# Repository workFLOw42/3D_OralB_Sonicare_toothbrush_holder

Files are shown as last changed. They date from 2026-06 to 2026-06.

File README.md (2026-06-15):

# Elektrischer Zahnbürstenhalter – frei konfigurierbar (Oral-B + Sonicare)

**Eigenentwicklung**: ein parametrischer Halter mit **1–4 frei konfigurierbaren
Fächern** (je Oral-B/Sonicare × Ständer/Laden), **Voronoi-Relief** außen und
**austauschbaren Voronoi-Einsteckgittern**.
Die gesamte Geometrie ist eigenständig in OpenSCAD (parametrisch) + Python
(Voronoi-Erzeugung, 3MF-Packen) konstruiert. Übernommen wurden **keine fremden
Modelle** – lediglich die *funktionalen Schnittstellenmaße* (Ladeöffnungen,
Zapfen, Ladehöhen) wurden an Referenzteilen vermessen, damit die Ladestationen
und Bürsten von Oral-B und Sonicare passen.

<p align="center">
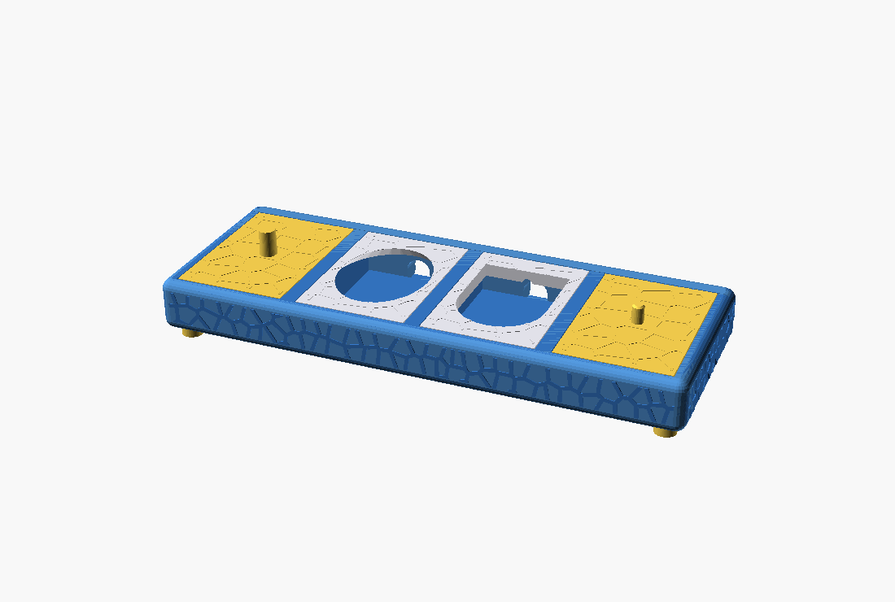
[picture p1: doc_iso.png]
Gesamtansicht
  <br>
  <em>Korpus mit den 4 eingesetzten Voronoi-Gittern</em>
</p>

## Über dieses Projekt

**Warum dieser Halter?**
Ladestationen für elektrische Zahnbürsten sind gerätespezifisch, und fertige Halter
passen meist nur zu *einem* Modell in *einer* Anordnung. Dieser Halter ist **frei
konfigurierbar**: 1–4 Fächer, je Fach wählbar für **Oral-B oder Sonicare** und als
**Ständer- oder Lade-Variante** – alles über Parameter, der Korpus wächst automatisch mit.

**Idee dahinter.**
Gleiches Design-Vokabular wie das Schwester-Projekt
[„Kabelbox"](https://github.com/workFLOw42/3D_Cable_box): **R5-Rundungen**, bündige
Flächen, **erhabenes Voronoi-Relief** und eine **werkzeuglose Schiebe-Mechanik**. Die
Funktionsflächen stecken in **austauschbaren Voronoi-Einsteckgittern**, die von hinten
eingeschoben werden – so lässt sich die Belegung später ändern, ohne den ganzen Korpus
neu zu drucken. Seit v2 sind die Einsätze **geschlossene Platten** mit dünnem, rein
optischem Voronoi-Relief (statt offenem Gitter).

**Status.** **Version 2.0** – funktionsfähig. Das jetzige Aussehen ist der Startpunkt;
das Projekt wird **bei Bedarf aktiv weiterentwickelt, überarbeitet und erweitert**
(weitere Geräte/Varianten, Feintuning der Spiele nach Probedrucken). Wie die Maße
zustande kommen, ist transparent in [`MEASUREMENTS.md`](MEASUREMENTS.md) dokumentiert.

---

## Inhalt
1. [Konzept](#konzept)
2. [Fächer-Belegung](#fächer-belegung)
3. [Maße](#maße)
4. [Funktionsprinzipien](#funktionsprinzipien)
5. [Projektdateien](#projektdateien)
6. [Bauen](#bauen)
7. [Parameter-Referenz](#parameter-referenz)
8. [Anpassen](#anpassen)
9. [Drucken](#drucken)
10. [Herkunft der Maße](#herkunft-der-maße)
11. [Lizenz](#lizenz)

---

## Konzept
- **Korpus** = rechteckige Wanne mit 4 Fächern in einer Reihe.
  - **Dünnes** Voronoi-**Relief** (erhaben, ~Lagen-dünn, rein optisch) auf Front + 2
    Seiten (Rückseite = Rückwand).
  - **Alle Außenkanten/Ecken mit R5 mm abgerundet**.
  - **Geschlossener Boden**; **hinten offen** für die einschiebbare Rückwand.
  - Steht auf **4 steckbaren Füßen** (separates Teil `foot.scad`, Ø10 × 5 mm + Zapfen
    Ø5 × 2 mm) – von unten in Bodensacklöcher gesteckt, stützenfrei.
- **Einsätze** = **geschlossene Platten** mit dünnem Voronoi-Relief obenauf,
  **von hinten eingeschoben** und per **Feder & Nut** gehalten (Schiebedeckel-Prinzip):
  seitliche **Lippen** an der Fach-Oberkante übergreifen die Einsatz-Oberkante → der
  Einsatz hebt sich beim Abziehen der Bürste **nicht** mehr mit. Oberseite bündig.
  - **Ständer**: zentraler **Zapfen** – die Bürste wird aufgesteckt.
  - **Laden**: Öffnung für die lose eingestellte Ladestation, die oben
    **flächenbündig mit dem Gitter** abschließt. Sonicare zusätzlich mit einer
    **halbrunden Kabelrinne** (5 × 2 mm) auf der Unterseite am geraden D-Ende.
  - **Ablage** (`tray`): komplett **geschlossene** Platte ohne Zapfen/Öffnung.
- **Rückwand** = separate Platte (10 mm tief, **bündig** mit den hinteren Eckpfosten)
  mit Voronoi-Relief, **von oben senkrecht** eingeschoben. Ihre **Feder vorn**
  (`rear_tongue_d`) greift in eine senkrechte Nut in den **massiven Eckpfosten**
  (Kabelbox-Stil) + Boden-Nut; dahinter ~5,7 mm Vollmaterial → sitzt **fest**. Sichert
  die Einsätze und trägt je Fach ein **kleines gerundetes Kabelloch** (12×9 mm).
- **Modular**: jedes Fach frei mit jedem passenden Gitter bestückbar; weitere
  Gitter-Varianten lassen sich leicht ergänzen.
- **Montage**: Ladestation in den Lade-Einsatz legen → Einsätze (inkl. Station) von
  **hinten** einschieben → Rückwand **von oben** einschieben. Demontage umgekehrt.
- **Orientierung**: mechanisch sind die Einsätze vorne/hinten symmetrisch (Lippe
  beidseitig). Nur der **Sonicare-Lade-Einsatz** hat eine Vorzugsrichtung – der
  **Bogen der D-Öffnung zeigt nach vorne**, die gerade Seite nach hinten (zur
  Rückwand). Ständer (runder Zapfen) und Oral-B-Laden (Ellipse) sind richtungsneutral.

---

## Fächer-Belegung (konfigurierbar)
**Anzahl Module (1–4) und Typ je Fach frei wählbar.** Standard 1×4, außen
**Ständer**, innen **Laden**:

| # | Position | Funktion | Marke | Öffnung / Feature | Gitter-Datei |
|---|---|---|---|---|---|
| 1 | außen | Ständer | Oral-B | ovaler Zapfen 8×9,6 → 7,5×9 mm | `grid0.stl` |
| 2 | innen | Laden | Oral-B | ovale Öffnung 42 × 55 mm (unten 45° aufgeweitet) | `grid1.stl` |
| 3 | innen | Laden | Sonicare | D-Kontur 40 × 55 mm (Halbkreis vorne) | `grid2.stl` |
| 4 | außen | Ständer | Sonicare | runder Zapfen Ø5,5 mm | `grid3.stl` |

Einstellbar in `params.scad`: `n_bays` (1–4) und `bay1..bay4`
(`stand_orb` / `charge_orb` / `stand_son` / `charge_son` / `tray` / `cup`). Der Korpus
passt seine Breite automatisch an. *(Hinweis: das Voronoi-Flächenrelief ist für 4 Fächer
vorberechnet und wird bei weniger Fächern vorne nur beschnitten; die Gitter-Muster
in den Fächern sind davon unabhängig.)*

<p align="center">
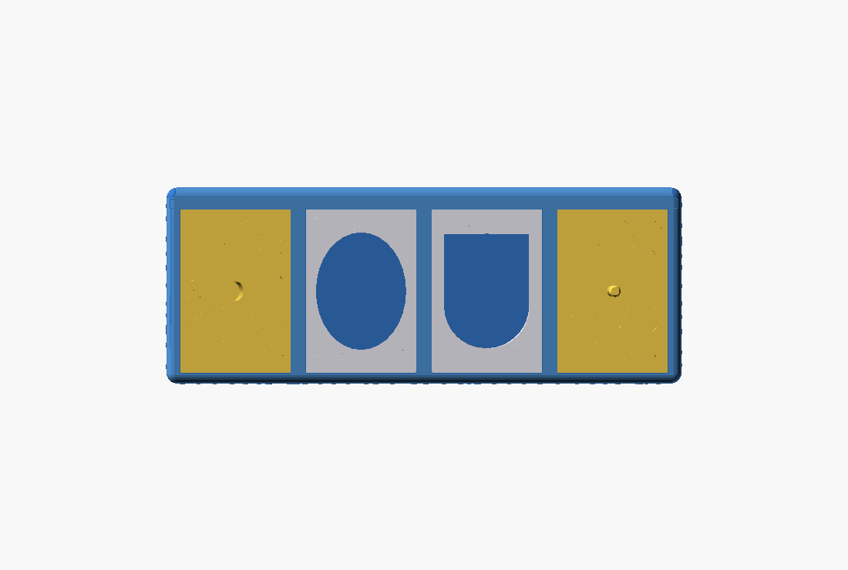
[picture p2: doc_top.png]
Draufsicht der 4 Fächer
  <br>
  <em>Draufsicht: Oral-B-Ständer (ovaler Zapfen) · Oral-B-Laden (Oval 41×54) ·
  Sonicare-Laden (D-Kontur 39×53) · Sonicare-Ständer (runder Zapfen Ø5,5)</em>
</p>

### Beispiel-Konfiguration: 2er (Becher + Ablage)
Ein fertig konfigurierter 2-Fach-Build (`n_bays=2`, `bay1="cup"`, `bay2="tray"`): ein
hoher **Becher** (Voronoi außen, gerundet, 80 mm) neben einer **Ablagefläche**
(geschlossen). Druckfertige Platte + Einzel-STLs liegen in
[`examples/2er-Becher-Ablage/`](examples/2er-Becher-Ablage)
(Platte 127,8 × 217,4 mm → passt auf X2D; Becher steht aufrecht, Rest liegt flach).

<p align="center">
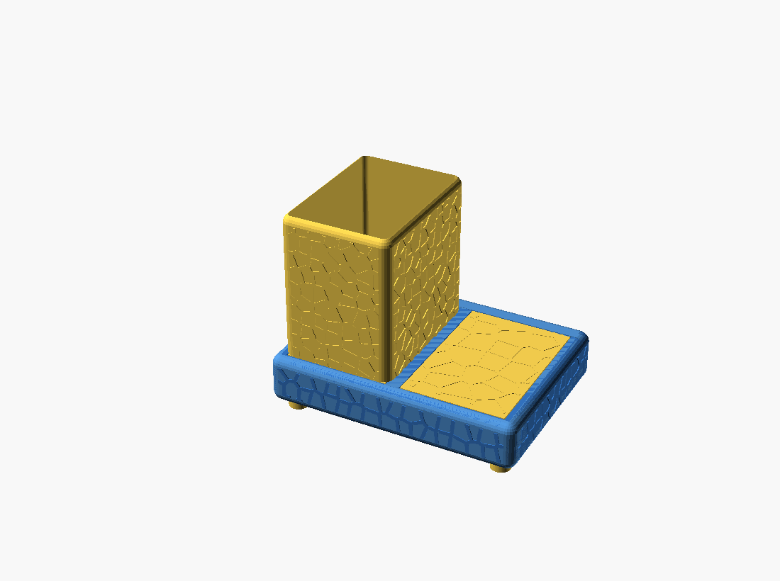
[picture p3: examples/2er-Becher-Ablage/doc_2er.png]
2er: Becher + Ablage
  <br>
  <em>2er: Becher (hoch, gerundet, Voronoi außen) + Ablagefläche (geschlossen)</em>
</p>

---

## Maße
| | Wert |
|---|---|
| Korpus außen (inkl. Relief) | **249,8 × 94,4 × 25 mm** (Wände v2 +1 mm) |
| + Füße | 5 mm → Gesamthöhe **30 mm** |
| Fach innen | 57 × 79 mm |
| Wandstärke | **5 mm** (Seitenwände) · zwei massive hintere Eckpfosten (10 mm) für die Rückwand-Nut · Boden 3 mm · Trennwand 3 mm |
| Kanten-/Eckradius | **R5 mm** (alle Außenkanten) |
| Füße (4×, steckbar) | Ø10 mm, 5 mm hoch + Zapfen Ø5 × 2 mm; Mitte 10 mm von den Rändern |
| Einsatz (geschlossene Platte) | 56,2 × ~79 × 6 mm + Zapfen/Öffnung, dünnes Relief oben |
| Druckplatte (alle Teile) | 249,8 × 196,6 mm → passt auf Bambu **X2D (256×256)** |

**Aus echten Referenzteilen gemessen** (Details → [Herkunft der Maße](#herkunft-der-maße)):

| Feature | Maß |
|---|---|
| Oral-B Laden (Ladering-Öffnung) | oval **41 × 54 mm** (Öffnung unten 45° aufgeweitet), Ladehöhe 21 mm |
| Oral-B Ständer-Zapfen | oval, verjüngt **8×10 → 7×9 mm**, h 14 mm |
| Sonicare Laden (Öffnung) | D-Kontur **39 × 53 mm** (Halbkreis vorne), Ladehöhe 20 mm; Kabelrinne 5×2 mm unten |
| Sonicare Ständer-Zapfen | rund **Ø 5,5 mm**, h 8,5 mm (Referenz Ø6,8) |

---

## Funktionsprinzipien

### Bündiges Laden
Lade-Fächer haben einen **erhöhten Boden** auf Höhe `body_height − charger_h`.
Die lose eingestellte Ladestation schließt damit oben **plan mit dem Einsatz** ab.
Da die Wände v2 um 1 mm höher sind (`body_height` 25), wächst der Ladestations-Sockel
automatisch mit (`pf = body_height − charger_h`), die Bündigkeit bleibt erhalten.
- Oral-B: Ladehöhe 21 mm → Oberkante 25 mm = bündig.
- Sonicare: Ladehöhe 20 mm → bündig.

Die **Oral-B-Ladeöffnung** weitet sich zur **Unterseite hin im 45°-Winkel** auf
(Einführtrichter): oben bleibt sie passgenau, unten wird das Einstellen des
Ladegeräts leichter.

### Ständer-Zapfen
Die Bürste wird mit ihrer hohlen Basis auf den Zapfen gesteckt.
- **Oral-B**: ovaler, sich leicht verjüngender Zapfen (`orb_peg_base`/`orb_peg_tip`).
- **Sonicare**: runder Zapfen Ø5,5 (`son_peg_d`), kleine Spitzenfase als Einführhilfe.
Beide mit umlaufendem Sockel (`peg_collar`) zur Anbindung an das Voronoi-Gitter.

<p align="center">
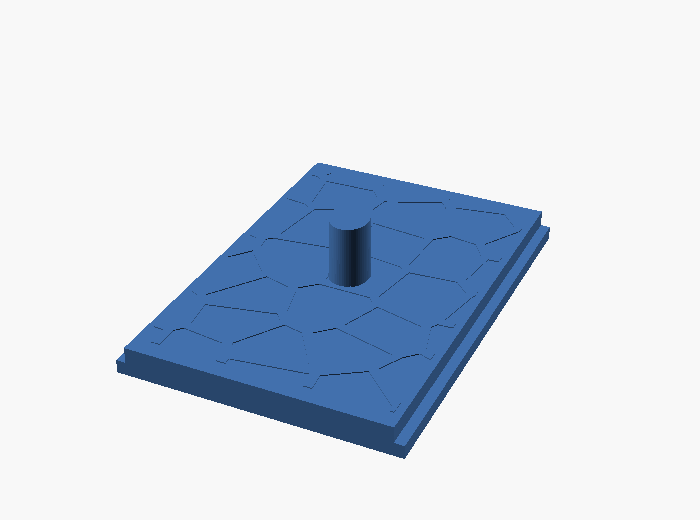
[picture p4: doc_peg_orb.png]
Oral-B Ständergitter mit ovalem Zapfen
  <br>
  <em>Oral-B-Ständereinsatz: ovaler, sich verjüngender Zapfen auf geschlossener Platte (dünnes Relief)</em>
</p>

### Abrundung & Füße
Der Korpus wird über `minkowski()` mit einer Kugel (R `fillet_r`) **allseitig
verrundet**. Das Flächen-Relief ist deshalb um `fillet_r` von den Kanten
eingerückt (sitzt auf den flachen Bändern). Die **vier Füße sind ein separates
Steck-Teil** (`foot.scad`, Ø10 × 5 mm + Zapfen Ø5 × 2 mm): Der Boden trägt nur
**Sacklöcher** (Ø5,1, 2 mm tief), die Füße werden von unten eingesteckt. Kein nach
unten zeigender Zapfen → alle Teile sind **ohne Stützen** druckbar.

### Einschiebbare Rückwand & Kabellöcher
Die Rückseite ist offen; eine **separate Rückwand** (10 mm tief, **bündig** mit den
hinteren Eckpfosten) wird von oben senkrecht eingeschoben. Ihre **Feder vorn**
(`rear_tongue_d`=4 mm) greift in eine senkrechte **Nut** in den **massiven Eckpfosten**
(Kabelbox-Stil) plus eine **Boden-Nut** (`floor_groove_d`). Hinter der Feder stehen
**~5,7 mm Vollmaterial** (weit weg von der gerundeten Hinterkante) → die Feder ist in Y
gefangen, die Rückwand sitzt **fest** (nur senkrecht entnehmbar). *(Bis v1.0 lag die Nut
in der dünnen Seitenwand mit nur 1,2 mm Anschlag, der beim Stützen-Entfernen brach – die
massiven Pfosten beheben das.)* Sie sichert die von hinten eingeschobenen Einsätze
gegen Herausrutschen, trägt das Voronoi-Relief der Rückseite und hat je Fach einen
**nach unten offenen Kabel-Schlitz** (`cable_hole_w` breit, gerundete Oberkante) –
so passt auch der **Stecker** durch (Rückwand wird beim Einschieben über das Kabel
gefädelt).

### Feder & Nut (Einsatz-Schiebehaltung)
Schiebedeckel-Prinzip (Vorbild Gridfinity): an der Fach-Oberkante stehen links/rechts
**Lippen** (`rail_overhang` nach innen) stehen; der Einsatz hat unten die volle
Breite (Feder) und schiebt von hinten darunter. So ist er vertikal gefangen und
hebt sich beim Abziehen der Bürste nicht. Spiel `rail_clear`.

### Voronoi
Seit v2 ist das Relief **dünn und rein optisch** (Deko, keine durchbrochenen Gitter):
- **Korpus-Flächen + Rückwand**: erhaben **0,4 mm** (`relief_h`, Zellraster `voro_cell_face`).
- **Einsätze**: **geschlossene Platte** + **0,2 mm** Relief obenauf (`relief_insert_h`,
  Zellraster `voro_cell`).
Die Muster werden von `gen_voronoi.py` (scipy) erzeugt und in `voronoi_data.scad`
geschrieben (`voro_face_long`, `voro_face_short`, `voro_insert`).

---

## Projektdateien
**Quelle (parametrisch):**

| Datei | Zweck |
|---|---|
| `params.scad` | **Alle Parameter** – einzige Wahrheitsquelle |
| `voronoi.scad` | 2D-Voronoi-Netz + Relief-Platzierung auf den 4 Flächen |
| `voronoi_data.scad` | **auto-generiert** – Voronoi-Kantensegmente (nicht von Hand ändern) |
| `body.scad` | Korpus: Wanne, Rundung, Boden-Sacklöcher (Füße), Fach-Lippen, Seitenwand-Nuten (Rückwand), Relief |
| `grid.scad` | Ein Einsatz (geschlossene Platte + Relief, T-Profil/Feder); Variante über `-D bay_index=0..3` |
| `rear_wall.scad` | separate Rückwand: Federn, Boden-Feder, Relief, Kabellöcher |
| `foot.scad` | separater Steck-Fuß (Zylinder + Zapfen nach oben) |
| `assembly.scad` | Vorschau: Korpus + Füße + 4 Einsätze + Rückwand (nur Ansicht) |
| `zahnbuersten_voronoi_makerworld.scad` | **EIN-DATEI** (alle Module inline) für **MakerWorld** – Customizer mit Belegung + Teil-Auswahl |

**Werkzeuge (Python):**

| Datei | Zweck |
|---|---|
| `gen_voronoi.py` | erzeugt `voronoi_data.scad` aus `params.scad` |
| `gen_makerworld.py` | erzeugt die MakerWorld-Einzeldatei aus den Quell-`.scad` |
| `pack_3mf.py` | packt alle STL flach auf eine Platte → `Zahnbuersten_Voronoi_4er.3mf` |
| `build.ps1` | kompletter Build (Daten → STL → 3MF → Vorschau) |
| `extract_profiles.py`, `measure2.py`, `ref_render.py`, `son_analyse.py` | Vermessung/Render der Referenzteile zur Schnittstellen-Maßnahme (Doku/Nachvollzug) |

**Ausgaben (druckfertig):**

| Datei | Inhalt |
|---|---|
| `Zahnbuersten_Voronoi_4er.3mf` | alle 6 Teile auf einer Platte (Bambu Studio) |
| `body.stl` | Korpus |
| `grid0.stl … grid3.stl` | die 4 Einsätze (siehe Belegungstabelle) |
| `grid4.stl` | **Ablage** (komplett geschlossener Einsatz, Einzeldatei) |
| `grid5.stl` | **Becher** (hoher gerundeter Behälter, Voronoi außen, Einzeldatei) |
| `rearwall.stl` | separate Rückwand |
| `foot.stl` | Steck-Fuß (4× drucken) |
| `doc_iso.png`, `doc_top.png`, `doc_peg_orb.png`, `assembly_back.png` | Vorschaubilder |

**Dokumentation:** `README.md` (diese Datei) · [`MEASUREMENTS.md`](MEASUREMENTS.md) (Mess-Herkunft) · [`CHANGELOG.md`](CHANGELOG.md) (Versionshistorie)

---

## MakerWorld (Customizer)
Für MakerWorlds **Parametric Model Maker** die **einzelne** Datei
`zahnbuersten_voronoi_makerworld.scad` hochladen (sie enthält alle Module inline –
die aufgeteilten `*.scad` mit `include` funktionieren dort nicht).

Customizer-Optionen:
- **Belegung**: `n_bays` (1–4) und `bay1..bay4` (OralB/Sonicare × Ständer/Laden,
  **`tray` = Ablage** (geschlossen) oder **`cup` = Becher** (hoch, gerundet)).
- **Teil-Auswahl** (`part`):
  - **`platte`** (Standard): **alle Teile druckfertig auf einer X2D-Platte**
    (Korpus + Einsätze + flach gelegte Rückwand + 4 Füße, < 256 × 256 mm).
  - `montage` (Vorschau), `korpus`, `gitter1..4`, `rueckwand`, **`fuss`** (Steck-Fuß),
    **`ablage`** (geschlossener Einsatz), **`becher`** (hoher Becher) – einzelne Teile.

---

## Bauen
**Voraussetzungen:** OpenSCAD (CLI) + Python mit `numpy scipy trimesh shapely rtree lxml`.

```powershell
# Toolchain (einmalig)
winget install --id OpenSCAD.OpenSCAD
python -m pip install numpy scipy trimesh shapely rtree lxml

# kompletter Build
./build.ps1
```

Einzelschritte:
```powershell
python gen_voronoi.py                              # Voronoi-Daten -> voronoi_data.scad
openscad -o body.stl body.scad                     # Korpus
openscad -D bay_index=0 -o grid0.stl grid.scad     # Einsatz (0..3)
openscad -D part_id=4 -o grid4.stl grid.scad       # Ablage (geschlossen)
openscad -D part_id=5 -o grid5.stl grid.scad       # Becher
python pack_3mf.py                                 # 3MF-Platte
```

> **Wichtig:** Nach Änderung von Korpus-/Fachmaßen oder Voronoi-Parametern
> immer zuerst `gen_voronoi.py` neu laufen lassen (das Relief-/Gittermuster
> hängt von den Maßen ab).

---

## Parameter-Referenz
Alle Werte in `params.scad`. „⟳" = nach Änderung `gen_voronoi.py` neu ausführen.

| Parameter | Default | Bedeutung | ⟳ |
|---|---|---|:--:|
| `n_bays` | 4 | Anzahl Fächer (1–4, konfigurierbar) | ⟳ |
| `bay1..bay4` | s. Belegung | Typ je Fach (`stand_orb`/`charge_orb`/`stand_son`/`charge_son`/`tray`/`cup`) | |
| `bay_inner_w` | 57 | Fach-Innenbreite X (mm) | ⟳ |
| `divider_t` | 3 | Trennwand zwischen Fächern | ⟳ |
| `wall_t` | 5 | Außenwandstärke (dick für bündige Rückwand-Nut) | ⟳ |
| `body_depth` | 79 | lichte Fachtiefe Y (Front..Rückwand) | ⟳ |
| `floor_t` | 3 | Bodenstärke | |
| `body_height` | 25 | Wandhöhe (= Boden + Oral-B-Ladehöhe + 1 mm) | ⟳ |
| `insert_h` | 6 | Dicke der Einsätze | |
| `ledge_w` | 2 | umlaufende Einsatz-Auflage | |
| `clearance` | 0,4 | Spiel Einsatz↔Fach pro Seite | |
| `fillet_r` | 5 | Radius aller Außenkanten | ⟳ |
| `foot_r` / `foot_h` / `foot_inset` | 5 / 5 / 5 | Fußradius / -höhe / Abstand v. Ecke | |
| `peg_d` / `peg_h` / `peg_hole_d` / `peg_hole_dep` | 5 / 2 / 5,1 / 2 | Steck-Fuß: Zapfen-Ø/-Höhe, Bodenloch-Ø/-Tiefe | |
| `rail_overhang` | 2 | Lippen-Überstand nach innen (Feder-Eingriff); max ~2,5 (Sonicare-Öffnung) | |
| `rail_thick` | 3 | Höhe der Lippe/Feder (Z) | |
| `rail_clear` | 0,25 | Spiel Feder↔Lippe | |
| `rear_wall_t` | 10 | Rückwand-/Pfostentiefe Y (Rückwand bündig mit Pfosten) | ⟳ |
| `rear_tongue_d` | 4 | Feder-Tiefe Y vorn (Eingriff in die Pfosten-Nut) | |
| `rear_tongue_w` / `rear_lead` | 2,5 / 1,5 | Rückwand-Federbreite (in Pfosten-Nut) / Einführfase | |
| `floor_groove_d` | 1,5 | Boden-Nut-Tiefe für die Rückwand | |
| `rear_clear` | 0,3 | Spiel Rückwand | |
| `cable_hole_w` / `cable_hole_h` | 12 / 11 | Kabel-Schlitz Breite / Oberkante über Boden (**unten offen**) | |
| `voro_seed` | 7 | Zufalls-Seed (deterministisch) | ⟳ |
| `voro_cell` | 12 | Zellabstand der Einsatz-Gitter | ⟳ |
| `voro_cell_face` | 7 | Zellabstand des Korpus-Reliefs | ⟳ |
| `voro_strut` | 1,8 | Stegbreite | |
| `relief_h` | 0,4 | Reliefhöhe Korpus + Rückwand (dünn, Deko) | |
| `relief_insert_h` | 0,2 | Reliefhöhe Einsätze (1 Lage) | |
| `charger_h_orb` / `charger_h_son` | 21 / 20 | Ladestationshöhen (bündig) | |
| `orb_charger_x` / `orb_charger_y` | 41 / 54 | Oral-B Ladeöffnung (Oval X/Y) | |
| `son_charger_x` / `son_charger_y` | 39 / 53 | Sonicare Ladeöffnung (D-Form X/Y, Halbkreis vorne) | |
| `son_charger_fit` | 1,0 | Spiel rundum für die Ladestation | |
| `son_cable_w` / `son_cable_h` | 5 / 2 | Sonicare-Kabelrinne (Unterseite, gerades D-Ende) | |
| `cup_h` / `cup_wall` / `cup_round` | 80 / 2,5 / 5 | Becher: Höhe / Wandstärke / Rundung | ⟳ |
| `orb_peg_base` / `orb_peg_tip` | [8,9.6] / [7.5,9] | Oral-B Zapfen Fuß/Spitze [X,Y] | |
| `orb_peg_h` | 12,5 | Oral-B Zapfen-Schafthöhe | |
| `son_peg_d` / `son_peg_h` | 5,5 / 8,5 | Sonicare Zapfen Ø / Höhe | |
| `peg_collar` | 2,5 | Sockel-Überstand am Zapfenfuß | |
| `peg_chamfer` | 0,8 | Fase an der Zapfenspitze | |
| `collar_t` | 3 | Kragen um Lade-Öffnungen | |
| `bays` | s. o. | Fächer-Belegung `[funktion, marke, label]` | |

---

## Anpassen
Typische Änderungen in `params.scad`:

- **Fachgröße/-anzahl**: `bay_inner_w`, `n_bays`, `body_depth` (Korpusbreite folgt automatisch). → ⟳
- **Voronoi-Look**: `voro_cell` / `voro_cell_face` (Dichte), `voro_strut` (Stegbreite), `relief_h` (Relieftiefe). → ⟳
- **Belegung**: `bays[...]` – pro Fach `["stand"|"charge", "orb"|"son", "Label"]`.
- **Ladestationen feinjustieren**: `charger_h_*` (Bündigkeit), `orb_charger_*` / `son_charger_*` (Öffnung), `son_charger_fit` (Spiel).
- **Zapfen feinjustieren**: `orb_peg_*`, `son_peg_*` (z. B. +0,2 mm für leichteren Sitz).
- **Schiebepassung**: `rail_clear` (Einsatz↔Lippe), `rear_clear` (Rückwand) – bei
  zu strammem Sitz nach dem Probedruck je +0,1 mm.
- **Kabelloch**: `cable_hole_w` / `cable_hole_h` / `cable_hole_z` (in `rear_wall.scad`).
- **Rundung/Füße**: `fillet_r` (⟳), `foot_*`.

Neue Gitter-Variante: in `grid.scad` eine weitere `funktion`/`marke`-Kombination
ergänzen (z. B. Sonicare-Lade-Recess mit Induktiv-Mulde) und in `bays` zuweisen.

---

## Drucken
Empfehlung (bewährtes Profil):
- **0,2 mm** Schichthöhe, **2 Wände**, **15 %** Infill (Grid), Textured PEI.
- **Korpus**: liegt auf den Füßen, offene Seite nach oben – i. d. R. **ohne
  Stützen** druckbar (Boden geschlossen, hinten offen). Die Fach-**Lippen** sind
  kurze (~2 mm) Überhänge an der Oberkante → bridgen i. d. R. ohne Stützen; bei
  Sagging Stützen nur für die Lippen-Unterseiten aktivieren.
- **Einsätze**: flach mit Zapfen/Relief nach oben – **keine Stützen** nötig.
- **Rückwand**: flach liegend drucken (Relief nach oben) – **keine Stützen**.
- **Füße (4×)**: stehend, **Zapfen nach oben** – stützenfrei; von unten in den Korpus stecken.
- **Mehrfarbig (optional)**: Korpus einfarbig, Einsätze/Rückwand in Kontrastfarbe.
- Alle Teile (inkl. 4 Füße) passen gemeinsam auf eine X2D-Platte
  (`Zahnbuersten_Voronoi_4er.3mf`, Bauraum 247,8×210,6 mm).

---

## Herkunft der Maße
Sämtliche funktionalen Maße wurden aus Referenz-3MF-Dateien
**gemessen, nicht geschätzt**. Nachvollzug und Methoden:
→ siehe **[MEASUREMENTS.md](MEASUREMENTS.md)**.

---

## Lizenz / Herkunft
**Eigenentwicklung.** Korpus, Voronoi-Relief und Einsteckgitter sind vollständig
eigenständig parametrisch konstruiert – es wurde **kein fremdes Modell als Basis
übernommen oder verändert**. Aus Referenzteilen stammen ausschließlich die
*funktionalen Schnittstellenmaße* (Ladeöffnungen, Zapfen, Ladehöhen); diese
sind durch die Geräte von Oral-B und Sonicare physikalisch vorgegeben, damit
Ladestationen und Bürsten passen.

**Lizenz: [CC BY-NC 4.0](LICENSE)** – Namensnennung, keine kommerzielle Nutzung. Frei für den privaten Gebrauch.

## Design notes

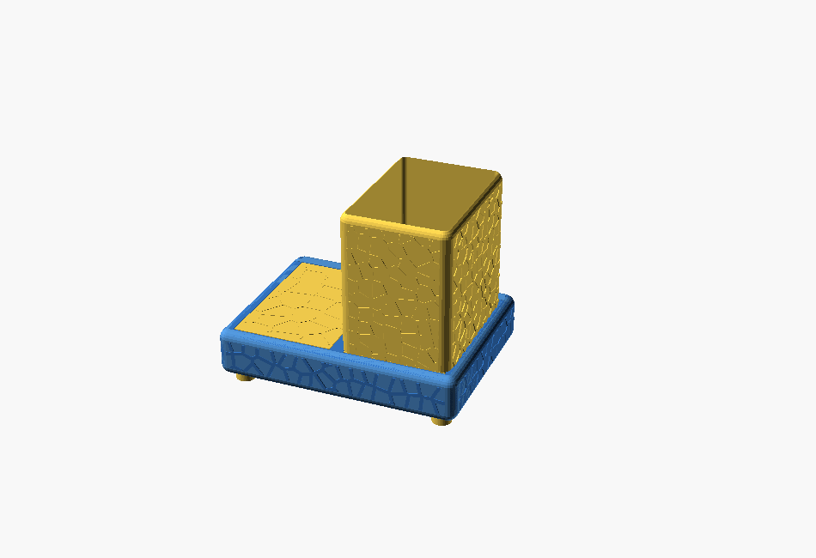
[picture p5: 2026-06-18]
renders/7_flaeche_becher.png

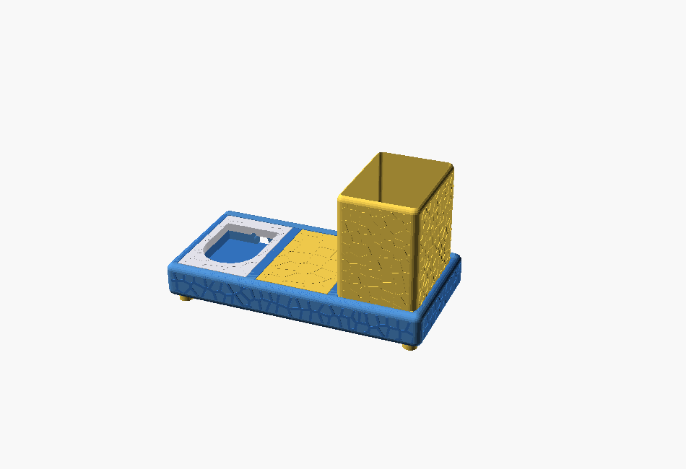
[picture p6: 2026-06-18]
renders/5_sonicare_laden_flaeche_becher.png

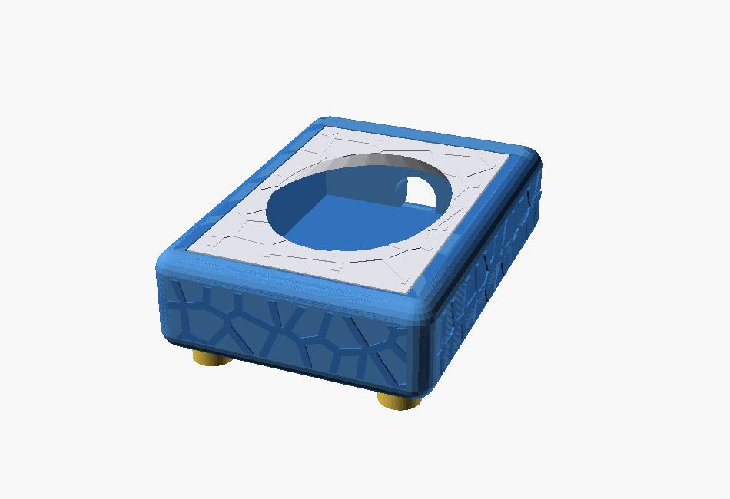
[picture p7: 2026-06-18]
renders/2_oralb_laden_einzeln.png

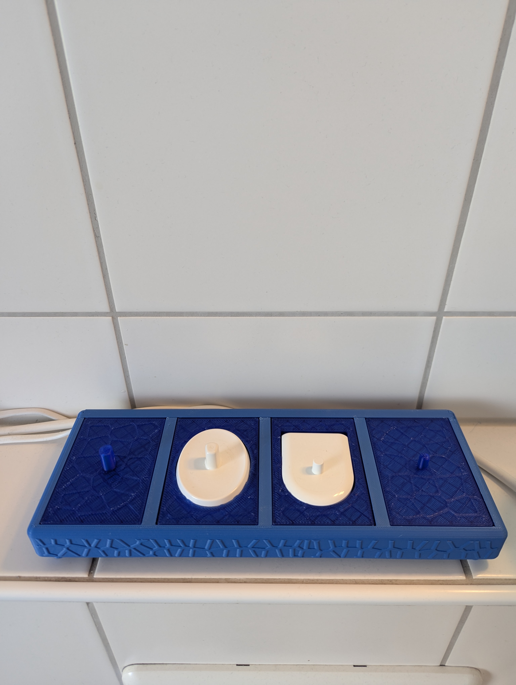
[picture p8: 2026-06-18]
renders/PXL_20260618_065032529.RAW-01.COVER.jpg

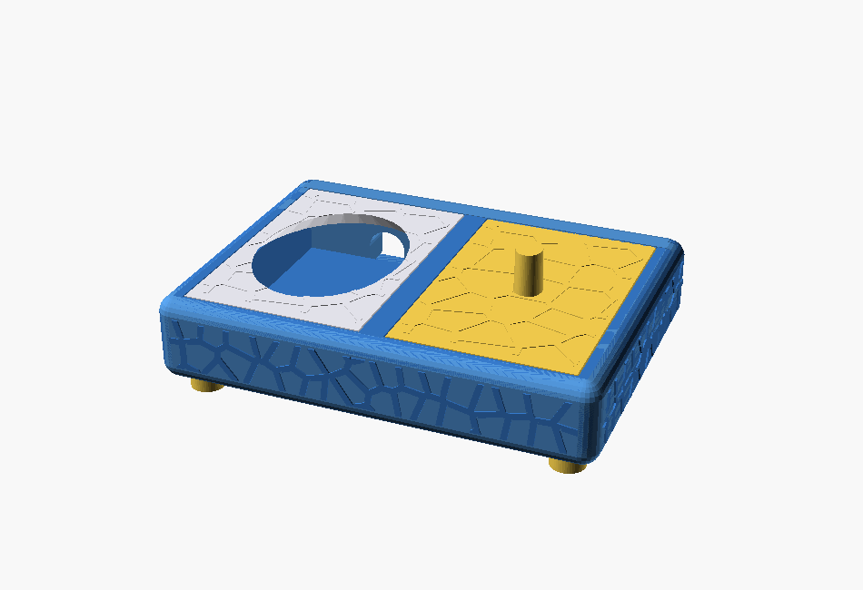
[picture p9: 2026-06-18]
renders/4_oralb_laden_staender.png

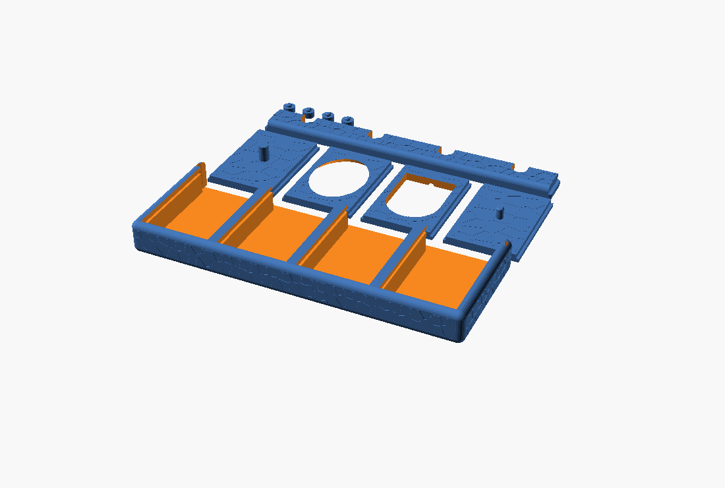
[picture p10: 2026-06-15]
doc_platte.png

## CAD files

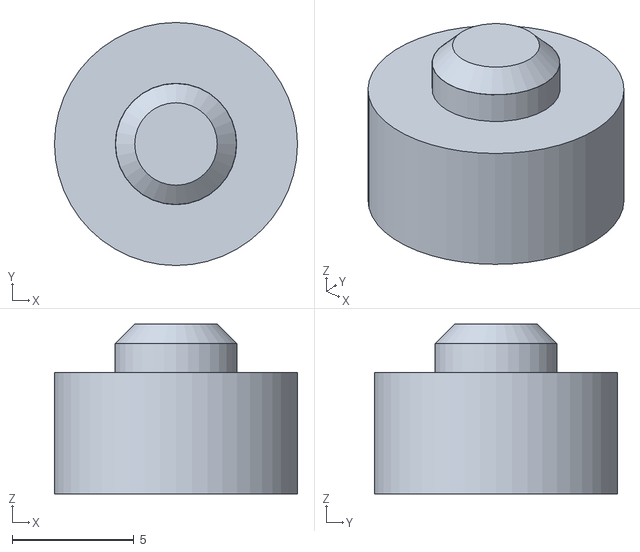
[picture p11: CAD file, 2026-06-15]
examples/2er-Becher-Ablage/foot.stl
10.0 x 10.0 x 6.99

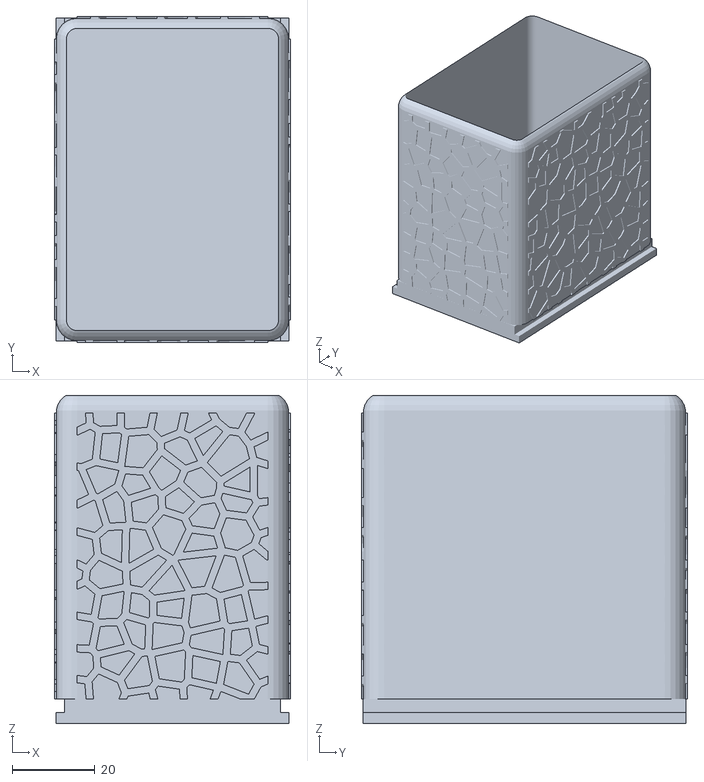
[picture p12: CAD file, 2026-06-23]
grid5.stl
57.0 x 78.7 x 79.3

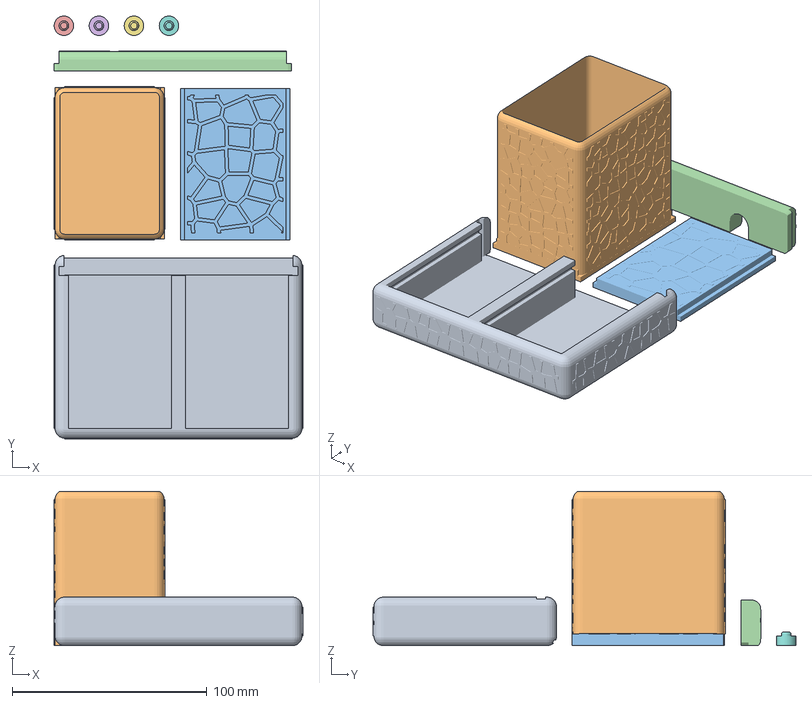
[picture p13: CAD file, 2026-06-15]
examples/2er-Becher-Ablage/Zahnbuersten_2er_Becher_Ablage.3mf
127.8 x 217.4 x 79.3 mm
Korpus_2er
Becher
Ablage
Rueckwand
Fuss_1
Fuss_2
Fuss_3
Fuss_4

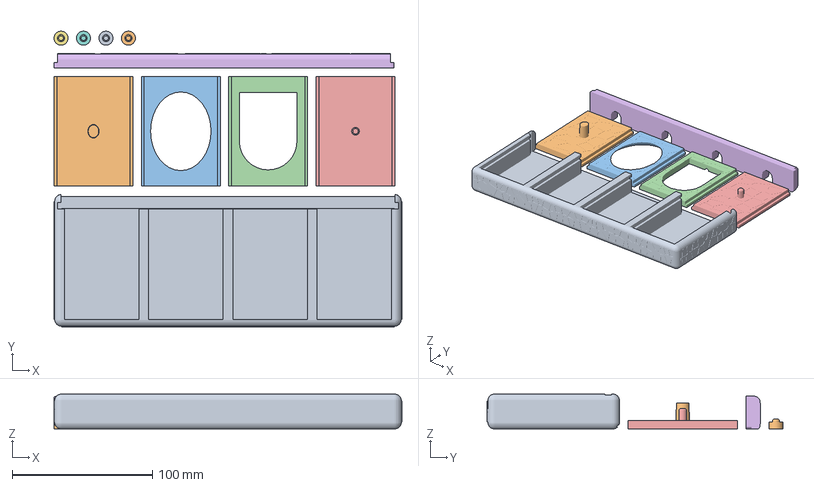
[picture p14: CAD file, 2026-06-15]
Zahnbuersten_Voronoi_4er.3mf
247.8 x 210.6 x 24.9 mm
Korpus_Voronoi
Gitter1_OralB_Staender
Gitter2_OralB_Laden
Gitter3_Sonicare_Laden
Gitter4_Sonicare_Staender
Rueckwand_Voronoi
Fuss_1
Fuss_2
Fuss_3
Fuss_4

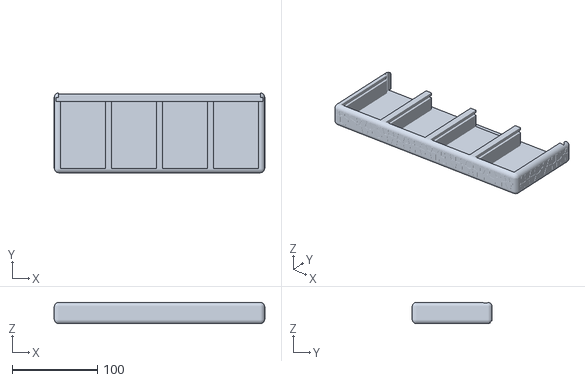
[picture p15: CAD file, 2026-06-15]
body.stl
247.8 x 94.3 x 24.9

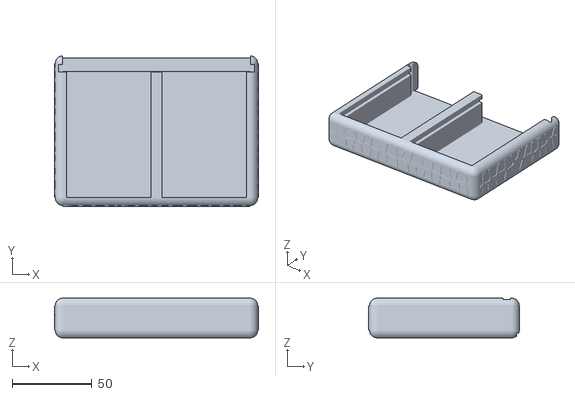
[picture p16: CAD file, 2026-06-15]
examples/2er-Becher-Ablage/body.stl
127.8 x 94.3 x 24.9

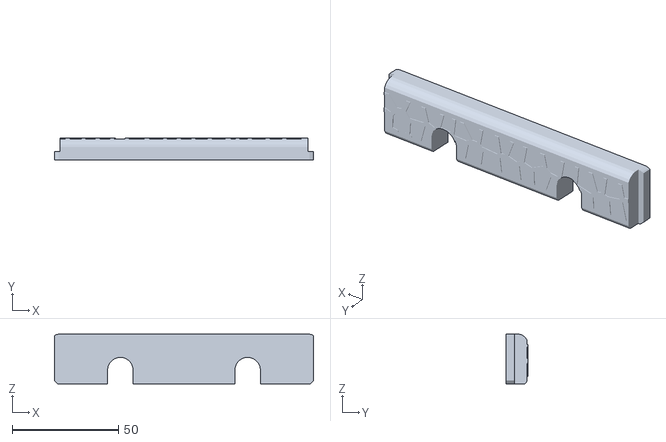
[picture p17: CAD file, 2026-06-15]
examples/2er-Becher-Ablage/rearwall.stl
122.0 x 10.4 x 23.5

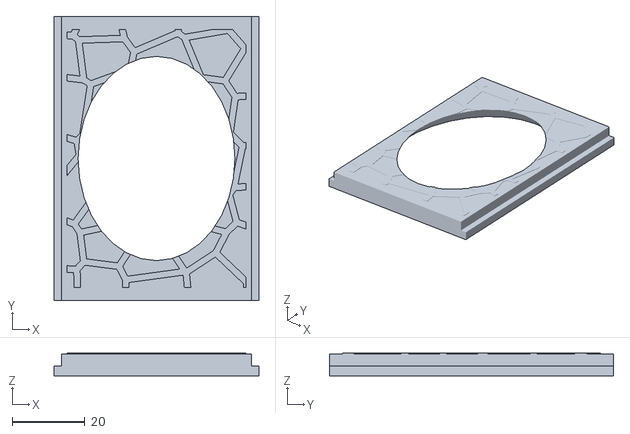
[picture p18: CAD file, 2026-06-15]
grid1.stl
56.2 x 77.9 x 6.20

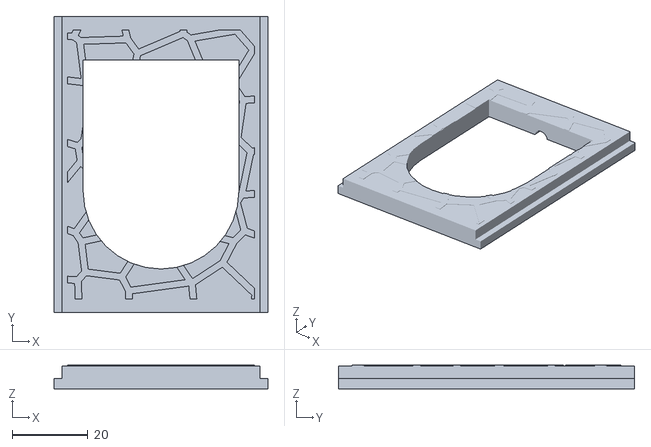
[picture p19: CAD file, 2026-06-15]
grid2.stl
56.2 x 77.9 x 6.20

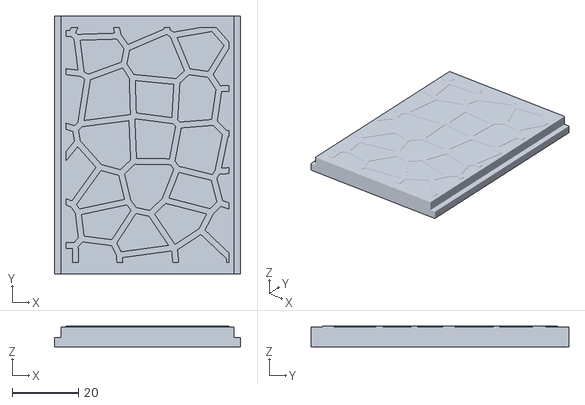
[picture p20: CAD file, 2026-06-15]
examples/2er-Becher-Ablage/grid1.stl
56.2 x 77.9 x 6.20

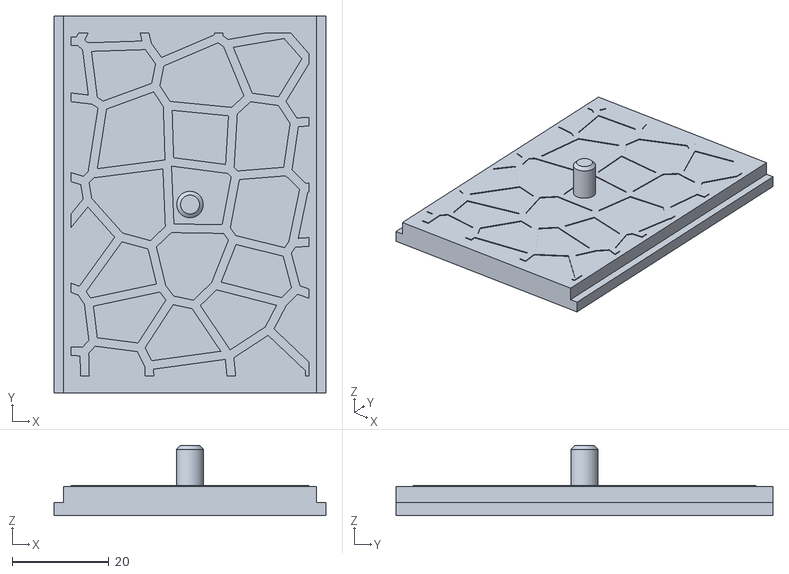
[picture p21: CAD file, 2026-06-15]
grid3.stl
56.2 x 77.9 x 14.5

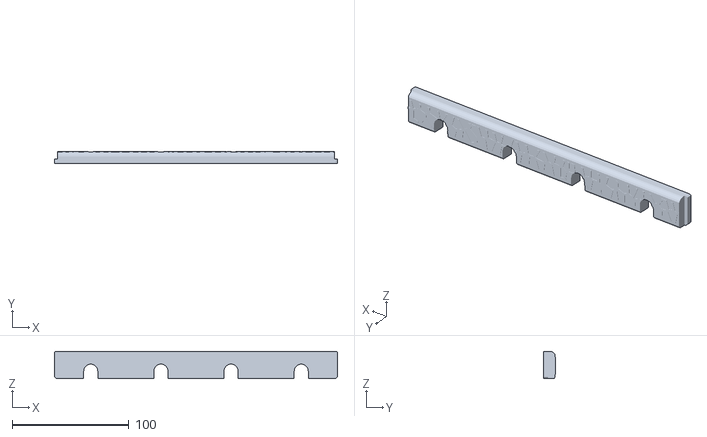
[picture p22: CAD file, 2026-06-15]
rearwall.stl
242.0 x 10.4 x 23.5

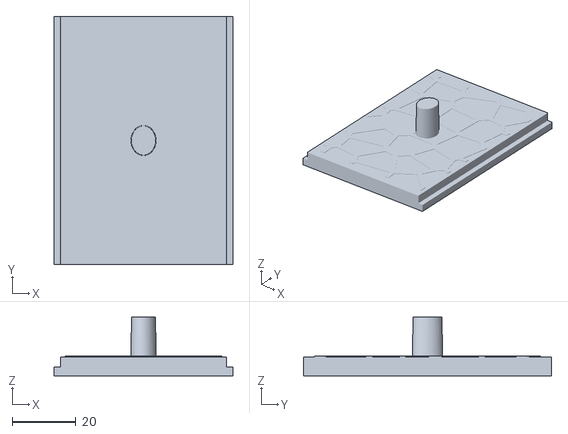
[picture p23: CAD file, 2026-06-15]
grid0.stl
56.2 x 77.9 x 18.5

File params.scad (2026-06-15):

// =====================================================================
//  params.scad  -  Zentrale Parameter (einzige Wahrheitsquelle)
//  Rechteckiger 4-Bürsten-Halter, Voronoi-Relief, modulare Einsätze.
//  Eigenentwicklung; nur die funktionalen Schnittstellenmaße an
//  Oral-B-/Sonicare-Referenzteilen vermessen (Geräte-Passung):
//    - Oral-B Cavity-Tiefe ~21 mm, Ladeöffnung oval 42x55, Zapfen 8x9,6->7,5x9
//    - Sonicare Ladeöffnung 40 x 55 mm (D-Form, Halbkreis vorne), Höhe 20 mm
// =====================================================================

// ---- Korpus (Wanne) -------------------------------------------------
//  (n_bays steht weiter unten in der Gruppe "Belegung")
bay_inner_w  = 57;    // Innenbreite je Fach in X (mm)
divider_t    = 3;     // Trennwand zwischen Fächern (mm)
wall_t       = 5.0;   // Außenwandstärke (mm) - dick genug für die bündige
                      //   senkrechte Rückwand-Nut in den Seitenwänden (statt Außenpfosten)
body_depth   = 79;    // lichte Fachtiefe in Y (Front-Innenkante .. Rückwand-Vorderkante)
floor_t      = 3.0;   // Bodenstärke (mm, jetzt geschlossen)
// Wandhöhe = Boden + größte Ladestationshöhe (+1 mm höhere Wände). Die Ladestationen
// bleiben über pf = body_height - charger_h bündig (Sockel wächst um 1 mm mit).
body_height  = 25;    // = floor_t(3) + Oral-B-Ladehöhe(21) + 1 mm höhere Wände

// ---- Einsatz-Sitz ---------------------------------------------------
insert_h     = 6.0;   // Dicke der Einsatzgitter (mm)
ledge_w      = 2.0;   // umlaufende Auflage für den Einsatz (mm)
clearance    = 0.4;   // Spiel Einsatz <-> Fach (mm, pro Seite)

// ---- Abrundung + Füße ----------------------------------------------
fillet_r     = 5.0;   // Radius aller Außenkanten/Ecken (0,5 cm)
foot_r       = 5.0;   // Fußradius (0,5 cm)
foot_h       = 5.0;   // Fußhöhe (0,5 cm)
foot_inset   = 5.0;   // Fußrand 0,5 cm von der Ecke (Mittelpunkt = inset+foot_r)

// ---- Steck-System: separate Füße (Kabelbox-Stil) -------------------
//  Füße werden von UNTEN in den Boden gesteckt (Zapfen zeigt nach oben ->
//  stützenfrei). Der Boden trägt nur Sacklöcher, kein nach unten zeigender Zapfen.
peg_d        = 5.0;   // Zapfen-Durchmesser
peg_h        = 2.0;   // Zapfen-Höhe (Steck-Tiefe)
peg_hole_d   = 5.1;   // Aufnahme-Loch im Boden (snug, +0,1 mm Spiel)
peg_hole_dep = 2.0;   // Sackloch-Tiefe im Boden (floor_t=3 -> 1 mm bleibt stehen)

// ---- Feder & Nut: Einsatz-Schiebehaltung (Gridfinity-Stil) ---------
//  Einsatz wird von HINTEN eingeschoben; seitliche Lippen an der Fach-
//  Oberkante übergreifen die Einsatz-Oberkante -> kein Abheben.
//  (rail_overhang darf 57-2*x > 51 lassen -> max ~2.5, sonst kollidiert die
//   Sonicare-Ladeöffnung 51 mit dem "Mund")
rail_overhang = 2.0;  // Lippen-Überstand nach innen (X) = Eingriff
rail_thick    = 3.0;  // Höhe der Lippe/Feder (Z) — kräftiger, gut sichtbar
rail_clear    = 0.25; // Spiel Feder <-> Lippe
rail_cham     = 0.8;  // 45°-Fase (stützenfreier Druck der Lippen-Unterseite)

// ---- separate Rückwand + hintere Eckpfosten (Kabelbox-Stil) --------
//  Die Rückwand ist so TIEF wie die hinteren Eckpfosten (rear_wall_t) -> hinten
//  BÜNDIG mit den Pfosten. Sie wird von OBEN senkrecht eingeschoben; ihre
//  seitliche Feder (rear_tongue_d tief, VORN an der Platte) greift in eine
//  senkrechte Nut in den massiven Pfosten. Dahinter steht rear_wall_t -
//  rear_tongue_d - rear_clear = 10 - 4 - 0,3 = 5,7 mm Vollmaterial (weit weg von
//  der gerundeten Hinterkante) -> Feder in Y gefangen, robust, kein dünner Steg.
rear_wall_t    = 10.0; // Platten-/Pfostentiefe (Y) -> Rückwand bündig mit Pfosten
rear_clear     = 0.3;  // Spiel Rückwand rundum
rear_tongue_w  = 2.5;  // Feder-Breite der Rückwand (X-Eingriff, in die Pfosten-Nut)
rear_tongue_d  = 4.0;  // Feder-Tiefe (Y) vorn an der Platte -> Eingriff in die Pfosten-Nut
rear_lead      = 1.5;  // Einführfase unten an der Rückwand-Feder
floor_groove_d = 1.5;  // Boden-Nut-Tiefe für die Rückwand-Unterkante

// ---- Kabelloch in der Rückwand: nach UNTEN offen (Stecker passt durch) -
cable_hole_w  = 12;   // Breite des Kabel-Schlitzes je Fach (X)
cable_hole_h  = 11;   // Oberkante des Schlitzes über dem Boden (Z), unten offen

// ---- Becher-Einsatz (grid5, "cup") ---------------------------------
//  Hoher Becher über die volle Einschub-Fläche, abgerundet, Voronoi außen.
//  Unten T-Profil-Basis (Schiebeführung wie die anderen Einsätze).
cup_h     = 80;    // Becher-Gesamthöhe (mm)
cup_wall  = 2.5;   // Becher-Wandstärke (mm)
cup_round = 5.0;   // Rundung (vertikale Kanten + obere Kante)

// ---- Voronoi --------------------------------------------------------
voro_seed     = 7;    // Zufalls-Seed (deterministisch)
voro_cell     = 12;   // Zellabstand Einsätze (mm)
voro_cell_face = 7;   // Zellabstand Korpus-Flächen (feiner, schmales Band)
voro_strut   = 1.8;   // Stegbreite (mm)
relief_h     = 0.4;   // Reliefhöhe Korpus + Rückwand (erhaben, ~2 Lagen, nur Deko)
relief_insert_h = 0.2; // Reliefhöhe Einschübe (1 Lage, Muster auf geschlossener Platte)

// ---- Ladestations-Maße (für flächenbündiges Abschließen) ------------
charger_h_orb = 21;   // Oral-B Ladestationshöhe (aus Referenz-Cavity ~21)
charger_h_son = 20;   // Sonicare Ladestationshöhe (gemessen)
// Oral-B Ladeöffnung: OVAL (Ellipse), aus chargeur-Gitter gemessen
orb_charger_x = 41;     // oval Breite (X, quer)  -- 1 mm schmaler
orb_charger_y = 54;     // oval Länge (Y)         -- 1 mm weniger tief
// Sonicare: D-Kontur (quer ins Fach). Vorne voller Halbkreis (Ø = Breite).
son_charger_x = 39;     // D-Breite (X, quer)     -- 1 mm schmaler
son_charger_y = 53;     // D-Tiefe (Y)            -- 2 mm weniger tief
son_charger_fit = 1.0;  // Spiel rundum für die Ladestation (mm)
// Kabelrinne an der GERADEN D-Kante, Unterseite des Sonicare-Einschubs
son_cable_w   = 5.0;    // Breite der halbrunden Kabelrinne (X)
son_cable_h   = 2.0;    // Höhe der Kabelrinne (Z, von der Unterseite hoch)

// ---- Ständer-Zapfen je Marke (Bürste aufstecken) -------------------
// Oral-B: OVALER, sich verjüngender Zapfen (Mesh-Schnitt Ladestation_OralB_ständer.3mf:
//   Fuß 8,05x9,58 -> Spitze ~7,5x9,0, Höhe 12,5 über Scheibe; Langachse Y)
orb_peg_base = [8, 9.6];    // [X quer, Y längs] am Fuß
orb_peg_tip  = [7.5, 9];    // an der Spitze (leichte Verjüngung)
orb_peg_h    = 12.5;        // Schafthöhe über dem Einsatz
// Sonicare: runder Zapfen Ø5,5 (gewuenscht; Referenz gemessen ~6,8)
son_peg_d    = 5.5;
son_peg_h    = 8.5;
peg_collar   = 2.5;       // ovaler/runder Sockel-Überstand am Fuß
peg_chamfer  = 0.8;       // kleine Fase an der Zapfenspitze

collar_t  = 3.0;  // Verstärkungs-Kragen um Lade-Öffnungen (mm)

// ---- Bay-Belegung (konfigurierbar) ---------------------------------
//  Anzahl Module + Typ je Fach. Typ = Funktion (Ständer/Laden) + Marke.
/* [Belegung] */
n_bays = 4; // [1,2,3,4]
bay1 = "stand_orb";  // [stand_orb:OralB Ständer, charge_orb:OralB Laden, stand_son:Sonicare Ständer, charge_son:Sonicare Laden, tray:Ablage, cup:Becher]
bay2 = "charge_orb"; // [stand_orb:OralB Ständer, charge_orb:OralB Laden, stand_son:Sonicare Ständer, charge_son:Sonicare Laden, tray:Ablage, cup:Becher]
bay3 = "charge_son"; // [stand_orb:OralB Ständer, charge_orb:OralB Laden, stand_son:Sonicare Ständer, charge_son:Sonicare Laden, tray:Ablage, cup:Becher]
bay4 = "stand_son";  // [stand_orb:OralB Ständer, charge_orb:OralB Laden, stand_son:Sonicare Ständer, charge_son:Sonicare Laden, tray:Ablage, cup:Becher]

// Typ-String -> [funktion, marke, label]
function _baytype(s) =
    s == "stand_orb"  ? ["stand",  "orb", "OralB-Staender"]    :
    s == "charge_orb" ? ["charge", "orb", "OralB-Laden"]       :
    s == "stand_son"  ? ["stand",  "son", "Sonicare-Staender"] :
    s == "charge_son" ? ["charge", "son", "Sonicare-Laden"]    :
    s == "tray"       ? ["tray",   "-",   "Ablage"]            :   // komplett geschlossen
                        ["cup",    "-",   "Becher"];   // hoher Becher, Voronoi außen
_baysel = [bay1, bay2, bay3, bay4];
bays = [ for (i = [0 : n_bays - 1]) _baytype(_baysel[i]) ];

// ---- abgeleitete Maße / Helfer (NICHT ändern) ----------------------
inner_w = n_bays*bay_inner_w + (n_bays-1)*divider_t;
outer_w = inner_w + 2*wall_t;
outer_d = wall_t + body_depth + rear_wall_t;         // Front-Wand + Fachtiefe + bündige Rückwand/Pfosten

// 4 Fuß-/Sackloch-Positionen (gemeinsame Wahrheitsquelle für Boden + Füße).
// WICHTIG: hintere Füße NICHT bei outer_d-m setzen — dort liegt der Rückwand-
// Schacht + die Boden-Nut (kein Vollmaterial -> Sackloch waere durchgaengig und
// der Zapfen kollidierte mit der Rueckwand). Daher knapp VOR die Rückwand (yr).
function foot_pts() = let (m = foot_inset + foot_r, yr = rear_wall_y0 - foot_r - 2)
    [[m, m], [outer_w - m, m], [m, yr], [outer_w - m, yr]];
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

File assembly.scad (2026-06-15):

// =====================================================================
//  assembly.scad  -  Vorschau: Korpus + 4 Einsätze (nur zur Ansicht)
// =====================================================================
include <params.scad>
include <voronoi_data.scad>
use <voronoi.scad>
use <body.scad>
use <grid.scad>
use <rear_wall.scad>
use <foot.scad>

color([0.20, 0.45, 0.75]) body();
color([0.95, 0.80, 0.30]) corner_feet();   // 4 steckbare Füße (unter dem Boden)

// Einsätze an Endposition (von hinten eingeschoben, vorne am Anschlag)
for (i = [0 : n_bays - 1]) {
    x0   = wall_t + i * (bay_inner_w + divider_t);
    fn   = bays[i][0];
    mk   = bays[i][1];
    col  = (fn == "charge") ? [0.90, 0.90, 0.93] : [0.95, 0.80, 0.30];
    color(col)
        translate([x0 + clearance, wall_t + clearance, body_height - insert_h])
            grid_insert(fn, mk);
}

// separate Rückwand (eingeschoben)
color([0.30, 0.55, 0.80]) rear_wall();

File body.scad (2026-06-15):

// =====================================================================
//  body.scad  -  Rechteckiger Korpus (Wanne) mit:
//   - allseitig abgerundeten Kanten/Ecken (R = fillet_r)
//   - geschlossenem Boden; HINTEN offen für die einschiebbare Rückwand
//   - Feder-&-Nut-Schiebehaltung der Einsätze: seitliche Lippen an der
//     Fach-Oberkante (Einsatz von hinten einschieben, Frontwand = Anschlag)
//   - zwei MASSIVE hintere Eckpfosten (Kabelbox-Stil, rear_wall_t tief). Die
//     senkrechte Rückwand füllt sie bündig; ihre Feder greift VORN in die Nut, DAHINTER der volle
//     Pfosten stehen (~5,7 mm) -> Feder in Y gefangen, kein dünner Steg/Anschlag,
//     der beim Stützen-Entfernen bricht.
//   - 4 Füßen; Voronoi-Relief (eingerückt) auf Front + 2 Seiten
// =====================================================================
include <params.scad>
include <voronoi_data.scad>
use <voronoi.scad>

// Vollkörper mit allseitig abgerundeten Kanten (Minkowski mit Kugel)
module rounded_block(w, d, h, r) {
    minkowski() {
        translate([r, r, r]) cube([w - 2*r, d - 2*r, h - 2*r]);
        sphere(r = r, $fn = 24);
    }
}

// Fach-Aushöhlung je Fach als 3-Band-Profil (endet an der Rückwand-Vorderkante;
// der Bereich dahinter wird von rear_cut geöffnet):
//   Band 1: unteres Fach (Ladestation/Auflage), schmaler -> Ledge
//   Band 2: Einsatzkörper, volle Fachbreite
//   Band 3: "Mund" oben, schmaler -> stehenbleibende Lippe übergreift den Einsatz
module bay_cutouts() {
    yb = wall_t;                 // Front-Innenkante (Frontwand bleibt Anschlag)
    yd = rear_wall_y0 - yb;      // Hohlraum endet an der Rückwand-Vorderkante
    for (i = [0 : n_bays - 1]) {
        fn = bays[i][0]; mk = bays[i][1];
        x0 = wall_t + i * (bay_inner_w + divider_t);
        pf = (fn == "charge") ? (body_height - charger_h(fn, mk)) : floor_t;
        // Band 1: unteres Fach (schmaler) -> umlaufende Auflage (Ledge)
        translate([x0 + ledge_w, yb, pf])
            cube([bay_inner_w - 2*ledge_w, yd, body_height]);
        // Band 2: Einsatzkörper (volle Breite)
        translate([x0, yb, body_height - insert_h])
            cube([bay_inner_w, yd, insert_h - rail_thick]);
        // Band 3: Mund (schmaler) -> Lippe bleibt an den Fachkanten stehen
        translate([x0 + rail_overhang, yb, body_height - rail_thick])
            cube([bay_inner_w - 2*rail_overhang, yd, rail_thick + 1]);
    }
}

// Rückwand-Aufnahme (Subtraktion):
//   - Plattenraum: volle Innenbreite bis zur Rückseite -> die rear_wall_t tiefe
//     Rückwand füllt ihn bündig; Trennwände enden vor der Rückwand (keine Stummel).
//   - zwei senkrechte Feder-Nuten VORN in den MASSIVEN Eckpfosten (nur rear_tongue_d tief).
//     Hinter der Nut bleibt der volle Pfosten stehen -> Feder in Y gefangen, robust.
//   - quer laufende Boden-Nut für die Plattenunterkante.
module rear_cut() {
    // Plattenraum (bis zur Rückseite durchgehend -> öffnet die Pfosten-Lücke)
    translate([wall_t - rear_clear, rear_wall_y0 - rear_clear, floor_t])
        cube([inner_w + 2*rear_clear,
              outer_d - rear_wall_y0 + rear_clear + 1, body_height + 1]);
    // seitliche Feder-Nuten (links/rechts) VORN im Pfosten (nur rear_tongue_d tief).
    xg0 = wall_t - rear_tongue_w - rear_clear;
    for (sx = [0, 1]) {
        gx = (sx == 0) ? xg0 : (outer_w - wall_t);
        translate([gx, rear_wall_y0 - rear_clear, floor_t - floor_groove_d])
            cube([rear_tongue_w + rear_clear, rear_tongue_d + 2*rear_clear,
                  body_height + 1]);
    }
    // Boden-Nut quer (Plattenunterkante)
    translate([wall_t - rear_tongue_w, rear_wall_y0, floor_t - floor_groove_d])
        cube([inner_w + 2*rear_tongue_w, rear_wall_t, floor_groove_d + 0.01]);
}

// Steck-System: der Boden trägt nur Sacklöcher (von unten) für die separaten
// Füße (siehe foot.scad) -> kein nach unten zeigender Zapfen, stützenfrei.
module foot_holes() {
    eps = 0.05;
    for (p = foot_pts())
        translate([p[0], p[1], -eps])
            cylinder(d = peg_hole_d, h = peg_hole_dep + eps, $fn = 32);
}

// Rundungs-Hülle für den Korpus: rundet ALLE Oberkanten sauber mit R5 (auch die
// eckig gefräste Nut-Oberkante hinten). XY um Relief-Aufmaß größer + nach unten weit
// offen -> Relief und Füße werden NICHT beschnitten.
module _body_round_env() {
    e = relief_h + 0.5;                       // XY-Aufmaß (Relief nicht clippen)
    minkowski() {
        translate([fillet_r - e, fillet_r - e, fillet_r - foot_h - 1])
            cube([outer_w - 2*fillet_r + 2*e, outer_d - 2*fillet_r + 2*e,
                  body_height - 2*fillet_r + foot_h + 1]);
        sphere(r = fillet_r, $fn = 24);
    }
}

module body() {
    intersection() {
        difference() {
            union() {
                rounded_block(outer_w, outer_d, body_height, fillet_r);
                // Voronoi-Relief (eingerückt um fillet_r) auf Front + 2 Seiten
                // (Rückseite trägt die separate Rückwand -> dort eigenes Relief)
                relief_front(outer_w, body_height, voro_face_long,  voro_strut, relief_h, fillet_r);
                relief_left (outer_d, body_height, voro_face_short, voro_strut, relief_h, fillet_r);
                relief_right(outer_w, outer_d, body_height, voro_face_short, voro_strut, relief_h, fillet_r);
            }
            bay_cutouts();
            rear_cut();
            foot_holes();
        }
        _body_round_env();
    }
}

body();

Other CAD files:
examples/2er-Becher-Ablage/grid0.stl
foot.stl
foot.scad
grid.scad
rear_wall.scad
voronoi.scad
voronoi_data.scad
zahnbuersten_voronoi_makerworld.scad

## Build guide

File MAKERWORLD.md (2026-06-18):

Ladestationen für elektrische Zahnbürsten sind gerätespezifisch, und fertige Halter passen meist nur zu **einem** Modell in **einer** Anordnung. Dieser Halter ist **frei konfigurierbar**: 1–4 Fächer, je Fach wählbar für **Oral-B oder Sonicare** und als **Ständer- oder Lade-Variante** – alles über Parameter, der Korpus wächst automatisch mit.

So lässt sich der Halter exakt auf den eigenen Haushalt zuschneiden: ein einzelnes Sonicare-Ladefach fürs Gäste-WC, ein Oral-B-Paar aus Lade- und Ständerplatz, oder die volle Reihe mit vier gemischten Fächern fürs Familienbad. Zwei Personen, zwei verschiedene Marken, ein Ständer zum Trocknen und ein Ladeplatz daneben? Kein Problem – die Belegung wird einfach pro Fach festgelegt.

**Funktionsweise.** Der **Korpus** ist eine rechteckige Wanne mit abgerundeten R5-Kanten, geschlossenem Boden und einem dünnen, rein optischen **Voronoi-Relief** auf Front und Seiten. Er steht auf vier steckbaren Füßen. Die eigentlichen Funktionsflächen stecken in **austauschbaren Einsätzen**, die von hinten eingeschoben und per Feder-&-Nut gehalten werden (Schiebedeckel-Prinzip) – beim Abziehen der Bürste hebt sich der Einsatz nicht mit. Eine separate, senkrecht eingeschobene **Rückwand** sichert die Einsätze und trägt je Fach ein kleines Kabelloch.

**Einsatz-Typen pro Fach:**
- **Laden** – Öffnung für die lose eingestellte Original-Ladestation, die oben flächenbündig abschließt (Oral-B: ovale Öffnung, Sonicare: D-Kontur mit halbrunder Kabelrinne).
- **Ständer** – zentraler Zapfen zum Aufstecken der Bürste zum Trocknen (Oral-B: ovaler, sich verjüngender Zapfen; Sonicare: runder Zapfen).
- **Ablage** – komplett geschlossene Platte, z. B. für Aufsteckbürsten oder Kleinkram.
- **Becher** – hoher Becher mit Voronoi-Außenwand, passt in ein Fach.

Alles ist **werkzeuglos zerlegbar**: Belegung später ändern heißt nur, einen Einsatz zu tauschen – nicht den ganzen Halter neu zu drucken. Es wurden **keine fremden Modelle** übernommen; lediglich die funktionalen Schnittstellenmaße (Ladeöffnungen, Zapfen, Ladehöhen) wurden an Referenzteilen vermessen, damit die Stationen und Bürsten von Oral-B und Sonicare passen.

**Profile.** Die mitgelieferten Profile decken die gängigen Anordnungen ab (z. B. Sonicare einzeln, Oral-B einzeln, Lade- + Ständer-Paare, sowie Kombinationen mit Ablage und Becher). Einfach das passende Profil wählen und drucken – oder im Customizer eine eigene Anordnung zusammenstellen.

### Selbst anpassen (Parametric Model Maker / Customizer)

Über **„Customize / Personalisieren"** lässt sich der Halter direkt im Browser umkonfigurieren – ohne OpenSCAD-Installation:

1. **`part` (Teil-Auswahl)** – legt fest, *was* erzeugt wird: `platte` druckt alle Teile fertig angeordnet auf einer Platte, `montage` zeigt die Zusammenbau-Vorschau, oder ein Einzelteil (`korpus`, `gitter1…4`, `rueckwand`, `fuss`, `ablage`, `becher`).
2. **`n_bays`** – Anzahl der Fächer (**1–4**). Der Korpus wird in der Breite automatisch passend erzeugt.
3. **`bay1`…`bay4`** – Typ je Fach. Auswahl pro Fach: *Oral-B Ständer*, *Oral-B Laden*, *Sonicare Ständer*, *Sonicare Laden*, *Ablage* oder *Becher*. Es zählen nur so viele `bay`-Felder wie `n_bays` gesetzt ist.

Ein typischer Ablauf: erst `n_bays` festlegen, dann jedem Fach über `bay1…bayN` einen Typ zuweisen, mit `part = platte` die Druckplatte erzeugen und slicen. Zum Nachdrucken eines einzelnen Einsatzes (z. B. wenn man später von Ständer auf Laden wechselt) einfach `part` auf das entsprechende `gitterN` stellen.

> Hinweis: Das Voronoi-Flächenrelief ist für 4 Fächer vorberechnet und wird bei weniger Fächern vorne nur beschnitten – das ist rein optisch und ändert nichts an der Passform.

---

Ich **freue mich über Feedback und Vorschläge** – ob Passungs-Erfahrungen nach dem Druck, Wünsche für weitere Geräte/Varianten oder Ideen zur Weiterentwicklung. Schreibt mir gern in die Kommentare!

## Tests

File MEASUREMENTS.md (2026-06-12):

# Herkunft der Maße (Provenance)

Dieser Halter ist eine **Eigenentwicklung** – die Geometrie ist vollständig
selbst konstruiert. Übernommen wurden nur die *funktionalen Schnittstellenmaße*
(Ladeöffnungen, Zapfen, Ladehöhen), die durch die Oral-B-/Sonicare-Geräte
physikalisch vorgegeben sind. Sie wurden aus Referenz-3MF-Dateien geometrisch
**vermessen, nicht geschätzt**. Diese Datei dokumentiert **Quelle, Methode und
Ergebnis** je Maß, damit alles nachvollziehbar/prüfbar ist.

## Referenzdateien (extern, nicht im Repo)
| Datei | Inhalt | genutzt für |
|---|---|---|
| `Ladestation_OralB_neu.3mf` | Referenzteil (Korpus + Gitter) | Oral-B Cavity-/Ladehöhe (~21 mm) |
| `Ladestation_OralB_Ladeloch.3mf` | „chargeur"-Gitter (Ladering) | Oral-B Ladeöffnung (oval) |
| `Ladestation_OralB_ständer.3mf` | „1b"-Ständergitter mit Zapfen | Oral-B Ständer-Zapfen |
| `Philips_Sonicare_Toothbrush_Holder_v2.3mf` | Sonicare-Ladestationshalter | Sonicare Ladestation (D-Kontur, Höhe) |
| `Ladestation_Aufsatz_Sonicare.3mf` | Sonicare-Ständergitter | Sonicare Ständer-Zapfen |

## Methoden
Alle Auswertungen mit **trimesh** (Mesh aus den `.model`-XML im 3MF gelesen) +
**scipy/numpy**:
- **BBox/Volumen**: direkte Mesh-Extents.
- **Aussparungen** (Becher/Recess): `mesh.voxelized(pitch).fill()` → 3D-Belegung;
  innere Leerregion je Schicht via `scipy.ndimage` (Label/Distanztransform).
- **Lochkonturen** (Ladeöffnungen): Oberflächen-Sampling → 2D-Belegungsraster →
  morphologisches Schließen (Lattice→Silhouette) → größte innere Leerregion.
- **Zapfenprofil**: Voxel-Schichten entlang der Zapfenachse; pro Höhe die
  zusammenhängende Voll-Strecke durch das Zentrum in X bzw. Z (Oval/Verjüngung).
Die Mess-Skripte und die Referenz-3MF sind **nicht Teil des Repos** (Fremdmodelle); Methodik und Ergebnisse oben dokumentieren alles Noetige.

---

## Ergebnisse

### Oral-B Ladehöhe / Cavity (aus `Ladestation_OralB_neu.3mf`)
- Referenzteil zum Kontext: 190 × 80 × 27 mm; 3 ovale Gitter (je ~65,7/56,1 × 74,6)
  pro Reihe. *(Nur als Vergleich – der hier entwickelte Korpus 249,8 × 88,4 × 24 ist eigenständig.)*
- Cavity-Tiefe (Fach) ≈ **21 mm** (Voxel-Analyse, Öffnung entlang der 27-mm-Achse)
  → entspricht der Oral-B-Ladestationshöhe (bündiger Abschluss).
- Übernommen: ovale Gitter-Grundfläche, modulares Stecksystem, Wandstärken-Größenordnung.

### Oral-B Ladeöffnung (aus `Ladestation_OralB_Ladeloch.3mf`, „chargeur"-Gitter)
- Gitter 56,1 × 3,0 × 74,6 mm (dünner Wabenring).
- Innere Öffnung (Lochkontur-Methode): **X ≈ 41,6 mm × Z ≈ 54,8 mm** → **oval ~42 × 55 mm**, Bandbreite ~7 mm.
- ⇒ `orb_charger_x = 42`, `orb_charger_y = 55` (Ellipse, nicht rund).
  > **v1.1-Anpassung:** Die Öffnung weitet sich im Modell **zur Unterseite hin im 45°-Winkel** auf (Einführtrichter; oben passgenau).

### Oral-B Ständer-Zapfen (aus `Ladestation_OralB_ständer.3mf`, object_16)
- Scheibe 65,7 × 16,0 × 74,6 mm (Wabenlattice); Scheibe Y −8…−4,5 (≈3,5 mm),
  zentrale Vollsäule (Zapfen) ragt Y −4,5…+8 heraus = **12,5 mm über Scheibe**.
- Methode: exakte Querschnitt-**Polygone** per `mesh.section` (nicht nur Sampling):

| Höhe ab Scheibe (mm) | X (kurz) | Y (lang) |
|---|---|---|
| 0 (Fuß) | 8,05 | 9,58 |
| ~4,5 (mitte) | 7,81 | 9,29 |
| ~12,5 (Spitze) | 7,5 | 9,0 |

- Form: **Ellipse** (Eck-Füllfaktor 0,13 ggü. Rechteck → keine gerundete
  Rechteckform nötig).
- ⇒ **ovaler, leicht verjüngender Zapfen**: Fuß ~8 × 9,6 → Spitze 7,5 × 9,0 mm,
  Höhe 12,5 (Langachse längs der Scheibe = Bay-Y).
  `orb_peg_base = [8, 9.6]`, `orb_peg_tip = [7.5, 9]`, `orb_peg_h = 12.5`.

### Sonicare Ladestation (aus `Philips_Sonicare_Toothbrush_Holder_v2.3mf`)
- Halterkörper (object_3) 125 × 25 × 65 mm, wasserdicht, Volumen 84 cm³ (große Aussparung, oben offen).
- Aussparung (Voxel-Analyse, öffnet entlang der 25-mm-Achse): Pocket-Querschnitt
  **63 × 51 mm**, **Tiefe ≈ 20 mm** (darunter ~5 mm Boden).
- ⇒ Sonicare-Ladestation **D-/Oval-Kontur 51 × 63 mm**, Höhe **20 mm**.
  `son_charger_x = 51`, `son_charger_y = 63`, `charger_h_son = 20`.
  Im Modell als **echte D-Kontur** (Rechteck + Halbkreis) umgesetzt.
  > **v1.1-Anpassung:** Modell-Öffnung an das reale Ladegerät angepasst und auf **40 × 55 mm** (Halbkreis vorne Ø40) verkleinert (`son_charger_x = 40`, `son_charger_y = 55`). Der Referenzwert 51 × 63 stammt aus dem Holder_v2-Mesh.

### Sonicare Ständer-Zapfen (aus `Ladestation_Aufsatz_Sonicare.3mf`, „centre 1B")
- Scheibe 56,1 × 11,0 × 74,6 mm; zentrale Vollsäule.
- Zapfenprofil (Querschnitt X×Z je Höhe): über die ganze Höhe **6,8 × 6,8 mm**
  (rund, keine Verjüngung); Fußbereich 15,6 × 11,6 (Sockel/Lattice).
- ⇒ **runder Zapfen Ø ≈ 7 mm** (Referenz).
  > **v1.1-Anpassung:** Zapfen im Modell auf **Ø5 mm** reduziert (`son_peg_d = 5`).
  > **v1.2-Anpassung:** Zapfen auf **Ø5,5 mm** vergrößert und **1,5 mm gekürzt** auf **8,5 mm** Schafthöhe (`son_peg_d = 5.5`, `son_peg_h = 8.5`).

### Schiebedeckel-Mechanik (Referenz `Gridfinity_Box_with_Slide_Lid…3mf`)
Vorbild für die Feder-&-Nut-Schiebehaltung der Einsätze. Aus exakten
Querschnitt-Polygonen (`mesh.section`) der Box/Deckel-Teile gemessen:
- **Lippen-Überstand** (Box-Oberkante, nach innen) ≈ **2,0 mm**.
- **Feder/Tongue-Dicke** (Deckelrand unter der Lippe) ≈ **2,4 mm**.
- **Spiel** Feder↔Lippe ≈ **0,2 mm**; alle Kanten mit ~45°-Fasen (stützenfrei).
- ⇒ übernommen als `rail_overhang = 2`, `rail_thick = 2.4`, `rail_clear = 0.25`.

---

## Toleranzen / Hinweise
- Voxel-/Sampling-Auflösung 0,25–0,5 mm ⇒ Messunsicherheit ~±0,4 mm.
- Werte sind in `params.scad` zentral und einzeln feinjustierbar (z. B. nach
  einem Probedruck Spiel an Zapfen/Öffnungen um 0,2–0,5 mm anpassen).
- Die „Fuß/Sockel"-Zeilen in den Zapfentabellen (sehr breite Werte am Grund)
  stammen teils aus angrenzenden Lattice-Stegen und sind nicht Teil des
  eigentlichen Zapfenschafts.

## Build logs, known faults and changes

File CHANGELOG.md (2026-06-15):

# Changelog

Versionshistorie des frei konfigurierbaren Zahnbürstenhalters. Format angelehnt an
[Keep a Changelog](https://keepachangelog.com/de/). Maße in mm.

## [2.1] – 2026-06-15 · Ablage als Einzeldatei + neuer Becher-Einsatz

### Neu
- **Ablage als Einzeldatei** `grid4.stl` (eigener Render über `-D part_id=4`); im
  4er-Sammel-3MF bewusst **nicht** enthalten.
- **Becher-Einsatz** `grid5` / Typ `cup`: hoher (`cup_h`=80 mm) Behälter über die
  **volle Einschub-Fläche**, **Voronoi-Relief auf den Außenwänden**, rundum
  **abgerundet** (`cup_round`), hohl/oben offen, unten T-Profil-Schiebebasis.
  Wählbar je Fach (`bayN="cup"`), als Einzeldatei (`-D part_id=5`) und im Customizer
  (`part="becher"`). Neue Params `cup_h`/`cup_wall`/`cup_round`, Voronoi-Felder
  `voro_cup_w`/`voro_cup_d`.
- Render-Dispatcher in `grid.scad` (`part_id`): −1 = Fach, 4 = Ablage, 5 = Becher.

## [2.0] – 2026-06-15 · Steck-System, flaches Relief, geschlossene Einsätze + Ablage

Umbau im Stil der Kabelbox v2. Stützenfreier, schlichterer Aufbau.

### Geändert
- **Voronoi-Relief flach** (rein optisch, ~Lagen-dünn): `relief_h` 1,4 → **0,4 mm**
  (Korpus + Rückwand); neuer `relief_insert_h` = **0,2 mm** (Einsätze).
- **Einsätze geschlossen** statt offenes Gitter: solide Platte (T-Profil für die
  Schiebeführung bleibt) mit **dünnem Voronoi-Relief oben**. Gilt **universal** für
  alle Einsatz-Typen (Ständer, Laden, Ablage). Ständer-Zapfen und Lade-Öffnungen
  bleiben funktional; bei „Laden" wird die Relief-Schicht über der Öffnung mitgeräumt.
- **Füße steckbar**: integrierte Füße entfallen; der Boden trägt **4 Sacklöcher**
  (Ø5,1, 2 mm tief), die Füße sind ein **separates Teil** (`foot.scad`, Zylinder Ø10
  × 5 mm + Zapfen Ø5 × 2 mm nach oben) und werden von unten eingesteckt. Kein nach
  unten zeigender Zapfen → stützenfrei.
- **Wände +1 mm** höher: `body_height` 24 → **25 mm** (Ladestationen bleiben über
  `pf = body_height − charger_h` bündig).

### Geändert · Geräte-Passung (Maße)
- **Sonicare-Ladeöffnung** 1 mm schmaler + 2 mm weniger tief: `son_charger_x` 40 → 39,
  `son_charger_y` 55 → 53.
- **Sonicare-Einsatz**: neue **halbrunde Kabelrinne** (5 mm breit × 2 mm hoch) auf der
  **Unterseite** am geraden D-Ende → Kabel liegt sauber nach hinten (`son_cable_w/h`).
- **Oral-B-Ladeöffnung** 1 mm schmaler + 1 mm weniger tief: `orb_charger_x` 42 → 41,
  `orb_charger_y` 55 → 54.

### Behoben
- **Hintere Füße kollidierten mit der Rückwand**: die hinteren Fuß-Sacklöcher lagen bei
  `outer_d − 10` = `rear_wall_y0` (84) und trafen dort auf den Rückwand-Schacht + die
  Boden-Nut → Loch durchgängig, kein Halt, Zapfen im Weg der Rückwand. `foot_pts()`
  setzt die hinteren Füße jetzt knapp **vor** die Rückwand (`yr = rear_wall_y0 − foot_r − 2`).

### Neu
- **Einsatz-Typ „Ablage"** (`tray`): komplett geschlossene Platte ohne Zapfen/Öffnung,
  je Fach wählbar (`bayN = "tray"`) und als eigenes Teil in der MakerWorld-Datei.
- **`gen_makerworld.py`**: erzeugt die MakerWorld-Einzeldatei reproduzierbar aus den
  Quellen. Customizer-Teile zusätzlich: `fuss` (Steck-Fuß) und `ablage`.
- `build.ps1` / `pack_3mf.py` bauen/packen jetzt auch die Füße.

## [1.2] – 2026-06-12 · Sonicare-Zapfen angepasst

### Geändert · Geräte-Passung (Maße)
- **Sonicare-Ständer-Zapfen** im Durchmesser auf **Ø5,5 mm** vergrößert
  (`son_peg_d` 5 → 5.5) und in der **Schafthöhe um 1,5 mm gekürzt** auf **8,5 mm**
  (`son_peg_h` 10 → 8.5). Betrifft den Sonicare-Ständer-Einsatz (`grid3.stl` in der
  Standard-Belegung).
- STL (`grid3`), 3MF und Vorschaubilder (`doc_iso`, `doc_top`) neu gebaut;
  MakerWorld-Einzeldatei gespiegelt.

---
## [1.1] – 2026-06-10 · Robuste hintere Eckpfosten + Geräte-Passung

### Geändert / Behoben
- **Rückwand-Halterung neu konstruiert** (Kabelbox-Stil): Die senkrechten Nuten sitzen
  jetzt in **zwei massiven hinteren Eckpfosten** statt in einer dünnen Seitenwand-Skin.
  Behebt den **Bruch der fragilen Nut-Anschläge** beim Entfernen der Stützstrukturen
  (Probedruck v1.0) – hinter der Nut steht jetzt **~5,7 mm Vollmaterial** (vorher 1,2 mm
  freistehender Steg). Modul `rear_stops()` entfällt.
- **Rückwand bündig**: Rückwand jetzt **10 mm tief** (`rear_wall_t`), schließt hinten
  **bündig mit den Pfosten** ab; **Feder vorn** (`rear_tongue_d`=4 mm) greift in die
  Pfosten-Nut. Voronoi-Relief läuft durchgehend über die Rückseite.
- **Gehäuse +6 mm tiefer in Y**: `body_depth` 78 → 79. Korpus außen **249,8 × 94,4 × 24 mm**
  (X unverändert). Fach-/Einsatz-Tiefe bleibt **78,7 mm**. Plattenlayout **249,8 × 196,6 mm**
  (< 256 × 256, Bambu X2D).
- **Parameter**: `rear_wall_t` 4 → 10, `rear_tongue_d`=4 neu; `rear_back_skin` entfällt.
- Voronoi-Seitenrelief neu erzeugt (Seitenflächen 78 → 84 mm). Alle STL/3MF neu gebaut;
  MakerWorld-Einzeldatei gespiegelt.

### Geändert · Geräte-Passung (Maße)
- **Sonicare-Ladeöffnung** an das reale Ladegerät angepasst: **40 × 55 mm**
  (vorher 51 × 63 mm), vorne voller **Halbkreis Ø40 mm**.
  `son_charger_x` 51 → 40, `son_charger_y` 63 → 55.
- **Sonicare-Ständer-Zapfen** auf **Ø5 mm** reduziert (`son_peg_d` 7 → 5).
- **Oral-B-Ladeöffnung** weitet sich jetzt **zur Unterseite hin im 45°-Winkel**
  auf (Einführtrichter; oben unverändert passgenau) – das Ladegerät lässt sich
  unten leichter einstellen. Neues Modul `charge_cut()` in `grid.scad`.
- STL `grid1/2/3`, 3MF und Vorschaubilder (`doc_iso`, `doc_top`, `assembly_back`)
  neu gebaut; MakerWorld-Einzeldatei gespiegelt.

---
## [1.0] – 2026-06-07 · Erste Veröffentlichung

Frei konfigurierbarer Halter für elektrische Zahnbürsten (Oral-B + Sonicare),
Eigenentwicklung in OpenSCAD + Python.

### Funktionen
- **Korpus**: rechteckige Wanne mit 1–4 Fächern, Voronoi-Relief auf Front + 2 Seiten,
  alle Außenkanten R5 gerundet, 4 Füße, geschlossener Boden. Seitenwände 5 mm dick.
- **Konfigurierbar**: `n_bays` (1–4) und je Fach ein Typ (`bay1..bay4`):
  Oral-B/Sonicare × Ständer/Laden. Belegung baut sich daraus; der Korpus skaliert
  automatisch in der Breite.
- **Einsätze (Feder & Nut, Schiebedeckel-Prinzip)**: seitliche Lippen an der
  Fach-Oberkante übergreifen die Einsatz-Oberkante (`rail_thick`=3, Überstand 2 mm).
  Einsatz wird **von hinten eingeschoben** und hebt sich beim Abziehen der Bürste
  **nicht** mehr mit. Front = Anschlag.
  - **Ständer**: Zapfen (Oral-B oval 8×9,6→7,5×9; Sonicare Ø7).
  - **Laden**: bündige Öffnung (Oral-B oval 42×55; Sonicare D-Kontur 51×63,
    **Bogen vorne**).
- **Separate Rückwand**: von oben senkrecht in **Nuten bündig in den Seitenwänden**
  + Boden-Nut eingeschoben; **Nut hinten geschlossen** → Rückwand sitzt **fest**.
  Folgt der R5-Gehäuserundung (oben/unten/hinten), trägt das Rückseiten-Voronoi-Relief
  und je Fach einen **nach unten offenen Kabel-Schlitz** (Stecker passt durch).
- **Montage**: Ladestation in den Lade-Einsatz legen → Einsätze (inkl. Station) von
  hinten einschieben → Rückwand von oben einschieben. Demontage umgekehrt.

### Maße (Standard 4 Fächer)
- Korpus außen 249,8 × 88,4 × 24 mm (+5 mm Füße), Fach innen 57 × 78 mm.
- Druckplatte aller Teile < 256 × 256 mm (Bambu X2D).

### Dateien / Toolchain
- Quelle (parametrisch): `params.scad` (Wahrheitsquelle) · `voronoi.scad` ·
  `voronoi_data.scad` (auto) · `body.scad` · `grid.scad` · `rear_wall.scad` ·
  `assembly.scad` (Vorschau).
- **MakerWorld**: `zahnbuersten_voronoi_makerworld.scad` – in sich geschlossene
  EIN-DATEI mit Customizer (Belegung + Teil-Auswahl). `part="platte"` legt alle
  Teile druckfertig auf eine X2D-Platte.
- Werkzeuge: `gen_voronoi.py` (scipy) → STL → `pack_3mf.py` → 3MF; `build.ps1`.
- Funktionale Maße aus Referenz-3MFs vermessen (durch die Geräte vorgegeben);
  siehe `MEASUREMENTS.md`. Geometrie ist Eigenentwicklung – kein Remix.

### Hinweis
- Das Voronoi-**Flächenrelief** ist für 4 Fächer vorberechnet; bei weniger Fächern
  wird es vorne nur beschnitten (rein optisch). Die **Gitter-Muster** in den Fächern
  sind unabhängig und immer korrekt.

---

## Vorab-Entwicklung (vor 1.0, 2026-06-06/07)
Kompakte Historie der Entwicklungsschritte:
- **Erstentwurf**: rechteckiger 4-Fach-Halter, Voronoi-Relief + Einsteckgitter.
- **Schnittstellen vermessen**: Sonicare D-Kontur 51×63 & bündiges Laden;
  Oral-B Ladeöffnung oval 42×55; Oral-B-Zapfen oval 8×9,6→7,5×9 (Mesh-Schnitt),
  Sonicare-Zapfen Ø7.
- **Form**: R5-Kantenrundung, 4 Füße, geschlossener Boden, Ständer-Zapfen.
- **Schiebehaltung**: Feder-&-Nut-Einsätze + separate, einschiebbare Rückwand
  (Nut bündig in den Seitenwänden, hinten geschlossen; unten offene Kabel-Schlitze).
- **Konfigurierbarkeit** + **MakerWorld-Einzeldatei** + **X2D-Plattenlayout**.
- Doku als Eigenentwicklung klargestellt (kein Remix/Redesign).

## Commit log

2026-06-08 Initial release v1.0
    [Zahnbuersten_Voronoi_4er.3mf, assembly.scad, body.scad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]
2026-06-08 Add .gitattributes (LF-Normalisierung, Binaerdateien)
    [body.stl, grid0.stl, grid1.stl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]
2026-06-09 Robuste hintere Eckpfosten fuer die Rueckwand (Kabelbox-Stil)
    Probedruck v1.0: die duennen Nut-Anschlaege (rear_stops) brachen beim Entfernen der Stuetzstrukturen. Die senkrechte Rueckwand-Nut sitzt jetzt in zwei massiven hinteren Eckpfosten; dahinter steht ~5,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
    - Gehaeuse +6 mm tief in Y (body_depth 78->79, neu rear_post_d=10); Korpus aussen 249,8x94,4x24, X unveraendert. Fach-/Einsatz-Tiefe bleibt 78,7 mm. Platte 249,8x190,6 (<256x256).
    - rear_back_skin entfaellt; gen_voronoi.py outer_d-Ableitung angepasst; Voronoi-Seitenrelief neu erzeugt (78->84 mm). Alle STL/3MF neu gebaut, MakerWorld-Einzeldatei gespiegelt, README+CHANGE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
    [Zahnbuersten_Voronoi_4er.3mf, body.scad, body.stl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]
2026-06-09 Rueckwand buendig mit den Pfosten + Feder wiederhergestellt
    Folge-Fix zu v1.1: die Rueckwand sass 6 mm zurueckversetzt hinter den Pfosten und die Feder war flaechenbuendig in die Platte integriert (wirkte 'verschwunden').
    - Rueckwand jetzt 10 mm tief (rear_wall_t 4->10), fuellt bis zur Pfosten-Rueckseite -> hinten buendig, Voronoi-Relief laeuft durchgehend ueber die Rueckseite.
    - Echte Feder vorn (rear_tongue_d=4) greift in die Pfosten-Nut; dahinter ~5,7 mm Vollmaterial (weit weg von der gerundeten Hinterkante) -> robust. rear_post_d entfaellt (= rear_wall_t).
    - outer_d bleibt 94 -> Voronoi-Daten und Gitter unveraendert. Fach-Tiefe 78,7 mm, Korpus 249,8x94,4x24 unveraendert. Platte 249,8x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
    [Zahnbuersten_Voronoi_4er.3mf, body.scad, body.stl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]
2026-06-10 v1.1 Geraete-Passung: Sonicare-Zapfen Oe5, Sonicare-Lader 40x55, OralB-Ladeoeffnung 45deg-Trichter
    - Sonicare-Staender-Zapfen son_peg_d 7 -> 5 mm
    - Sonicare-Ladeoeffnung son_charger 51x63 -> 40x55 (Halbkreis vorne Oe40)
    - OralB-Ladeoeffnung weitet sich zur Unterseite im 45deg auf (neues Modul charge_cut)
    - grid1/2/3.stl + 3MF neu gebaut; MakerWorld-Einzeldatei gespiegelt
    - Vorschaubilder doc_iso/doc_top/assembly_back neu gerendert
    - README Status -> 1.1, CHANGELOG 1.1 ergaenzt, MEASUREMENTS Override-Hinweise
    [Zahnbuersten_Voronoi_4er.3mf, grid.scad, grid1.stl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]
2026-06-12 v1.2 Sonicare-Zapfen: Oe5,5 (son_peg_d 5->5.5), Hoehe 1,5mm niedriger (son_peg_h 10->8.5)
    Doku (README, MEASUREMENTS, CHANGELOG, grid.scad-Kommentar) angepasst;
    grid3.stl, 3MF und Vorschaubilder (doc_iso, doc_top) neu gebaut.
    [Zahnbuersten_Voronoi_4er.3mf, grid.scad, grid3.stl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]
2026-06-15 v2.0: Steck-System, flaches Relief, geschlossene Einsaetze + Ablage
    Umbau im Stil der Kabelbox v2:
    - Voronoi-Relief flach/Deko: relief_h 1.4->0.4 (Korpus/Rueckwand),
    relief_insert_h 0.2 (Einsaetze)
    - Einsaetze geschlossene Platte + duennes Relief (universal: stand/charge/tray)
    - Fuesse steckbar: foot.scad (Zapfen oben) + 4 Boden-Sackloecher, stuetzenfrei
    - Waende +1 mm (body_height 25), Ladestationen bleiben buendig (Sockel waechst mit)
    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
    [Zahnbuersten_Voronoi_4er.3mf, assembly.scad, body.scad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]
2026-06-15 Fix: hintere Fuesse kollidierten mit der Rueckwand
    Die hinteren Fuss-Sackloecher lagen bei outer_d-10 = rear_wall_y0 (84) und
    trafen dort auf den Rueckwand-Schacht + die Boden-Nut -> Loch durchgaengig,
    kein Halt fuer den Zapfen, Kollision mit der Rueckwand. foot_pts() setzt die
    hinteren Fuesse jetzt knapp vor die Rueckwand (yr = rear_wall_y0 - foot_r - 2).
    body.stl/3MF/MakerWorld/Vorschau neu gebaut.
    [Zahnbuersten_Voronoi_4er.3mf, body.stl, params.scad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]
2026-06-15 v2.1: Ablage als Einzeldatei (grid4) + neuer Becher-Einsatz (grid5)
    - Ablage jetzt eigene STL grid4.stl (-D part_id=4); nicht im 4er-3MF.
    - Becher (Typ "cup", grid5): hoher Behaelter ueber die volle Einschub-Flaeche,
    cup_h=80, Voronoi-Relief auf den Aussenwaenden, rundum abgerundet (cup_round),
    hohl/oben offen, unten T-Profil-Schiebebasis. Je Fach waehlbar (bayN="cup"),
    Einzeldatei (-D part_id=5), Customizer-Teil "becher".
    - Fix cup_outer: ueberfluessiges translate verschob die Schale um r -> Relief
    schwebte vor der Wand; jetzt Footprint exakt 0..w/0..d, Relief verschmolzen.
    - params: cup_h/cup_wall/cup_round; gen_voronoi: voro_cup_w/voro_cup_d.
    - grid.scad Render-Dispatcher part_id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
    [Zahnbuersten_Voronoi_4er.3mf, grid.scad, grid4.stl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]
2026-06-15 Beispiel-Konfiguration: 2er (Becher + Ablage)
    Fertiger 2-Fach-Build (n_bays=2, bay1=cup, bay2=tray): hoher Becher + Ablage.
    - examples/2er-Becher-Ablage/: 3MF-Druckplatte (127,8x217,4 mm, X2D) + Einzel-STLs
    (body/grid0=Becher/grid1=Ablage/rearwall/foot) + Render doc_2er.png
    - README: Beispiel-Abschnitt mit Bild; bay-Optionen tray/cup ergaenzt;
    Draufsicht-Caption auf aktuelle Oeffnungsmasse (41x54 / 39x53)
    [Zahnbuersten_2er_Becher_Ablage.3mf, body.stl, foot.stl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]
2026-06-18 Doku: MakerWorld-Beschreibung (MAKERWORLD.md) + Render-Varianten
    - MAKERWORLD.md: ausfuehrliche Beschreibung mit Customizer-Anleitung
    (part / n_bays / bay1..bay4) und Feedback-Hinweis
    - renders/: 7 ISO-Vorschauen der gaengigen Belegungs-Varianten
2026-06-23 Fix: Becher (grid5) bekam keine Einschub-Lippe
    Die Aussenschale (cup_outer) war ueber die volle Hoehe volle Breite und
    fuellte den schmalen T-Profil-Bereich wieder auf -> keine Einkerbung, in
    die die Fach-Lippe greift. Neues Modul cup_clip zwingt die Schale unter
    insert_h auf das T-Profil (volle Breite unten = Feder, schmaler oben um
    rail_overhang), oberhalb bleibt sie voll (Wand/Relief unberuehrt).
    MakerWorld-Einzeldatei neu generiert; Becher byte-identisch zum Einzelteil.
    [grid.scad, grid5.stl, zahnbuersten_voronoi_makerworld.scad]
